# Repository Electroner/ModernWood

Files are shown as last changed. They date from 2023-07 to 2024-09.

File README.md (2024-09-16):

# ModernWood keyboard  

En este repositorio encontrarás desde los datasheet de cada parte que he usado hasta los archivos originales del AutoCAD, con todos los archivos descargados deberías ser capaz de poder crear y manufacturar este teclado sin ningún problema.

Este teclado usa un ESP32-S3 como controlador y un decodificador/Demultiplexor 74HC154D 4-a-16, Suficiente para conseguir un tiempo de polling igual o superior a los mejores teclados comerciales actuales (20kHz). Pruebas realizadas con el código actual. Además se ha decidido "prescindir" de un teclado numérico real, y lo que se ha hecho es conectar los números del numpad a los números de la parte superior del teclado, por lo que las teclas tanto del numpad como los de la parte superior son los mismos, al igual con el intro y "." (Ver Esquemática).

Para el cuerpo del teclado se ha optado por omitir de forma completa el Plate o panel superior, ya que dificulta el mantenimiento y el montaje. Se ha optado solo por poner una ventana de metacrilato en la parte de la electrónica para cubrirla de forma semicompleja y protegerla de golpes. La base del teclado es de madera. Esta será la que más guste al usuario, aunque se recomiendan jatoba, sucupira o mansonia.

Este además dispone de una pantalla donde se encontraran todas las configuraciones del teclado, además de la opción para habilitar o deshabilitar el funcionamiento por bluetooth.

## Imagenes

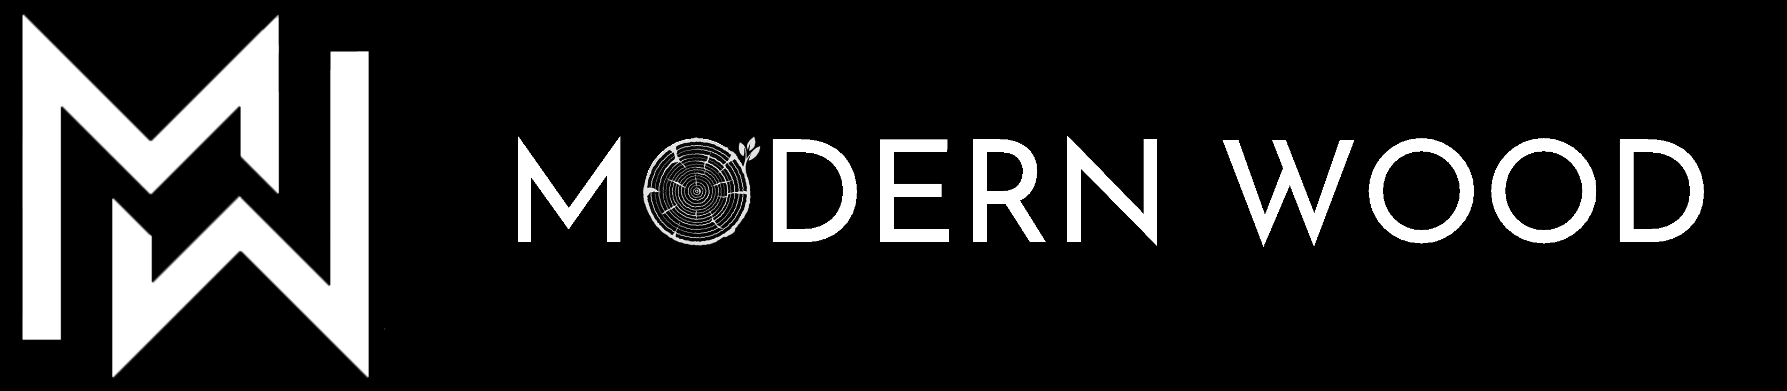
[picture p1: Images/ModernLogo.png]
TECLADO


---------------------------------------------------------------------------------------------

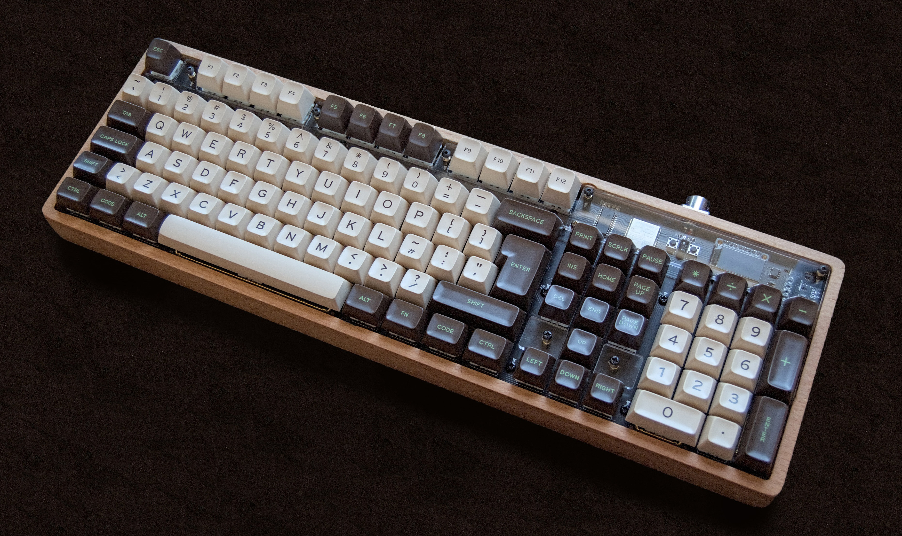
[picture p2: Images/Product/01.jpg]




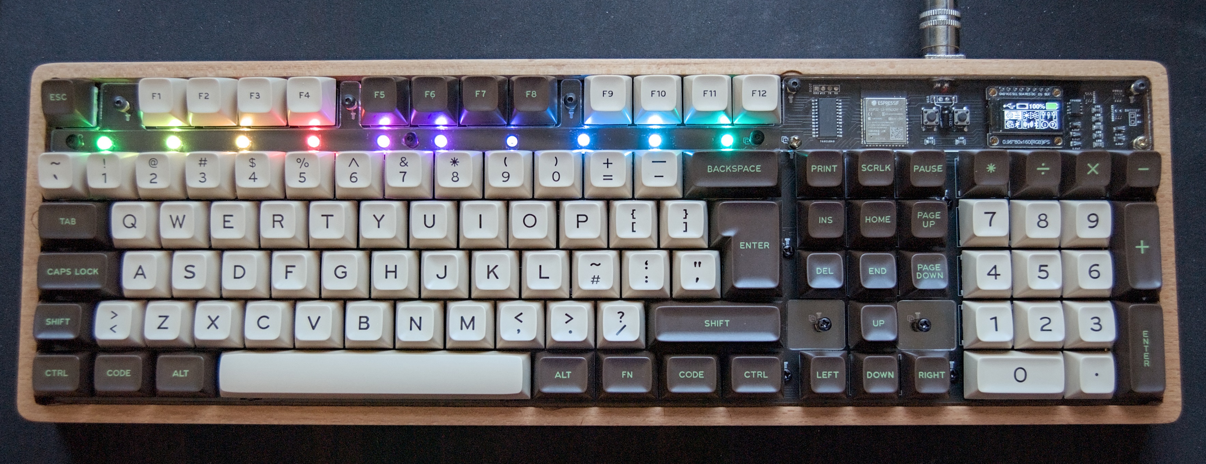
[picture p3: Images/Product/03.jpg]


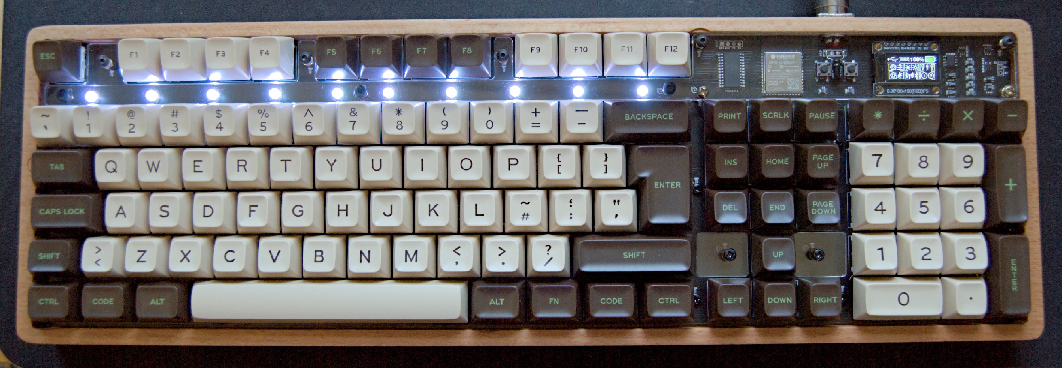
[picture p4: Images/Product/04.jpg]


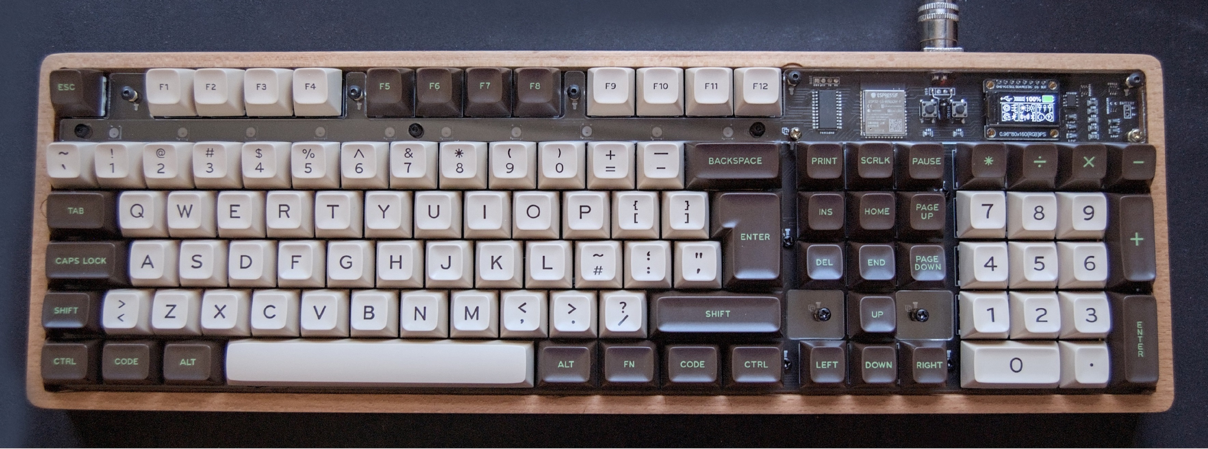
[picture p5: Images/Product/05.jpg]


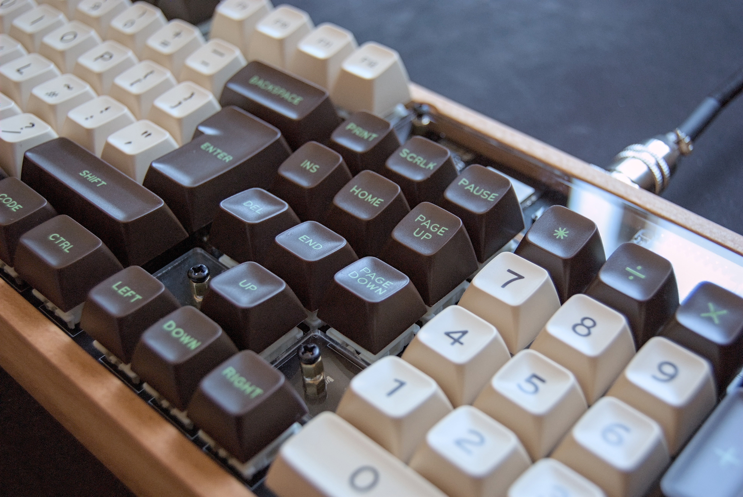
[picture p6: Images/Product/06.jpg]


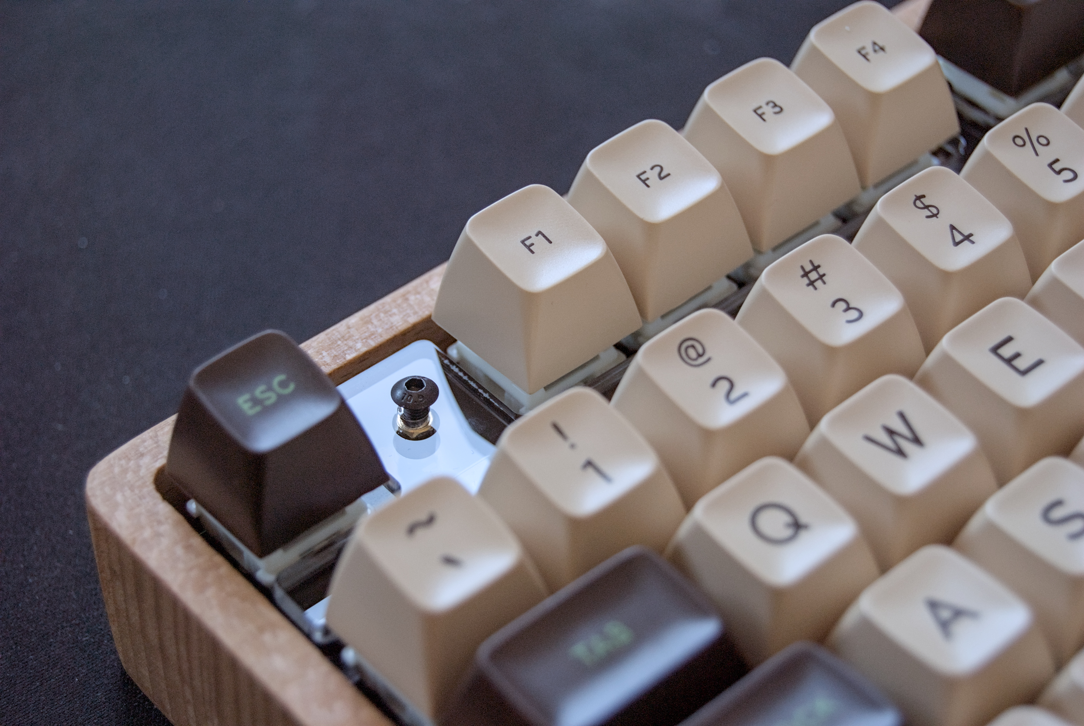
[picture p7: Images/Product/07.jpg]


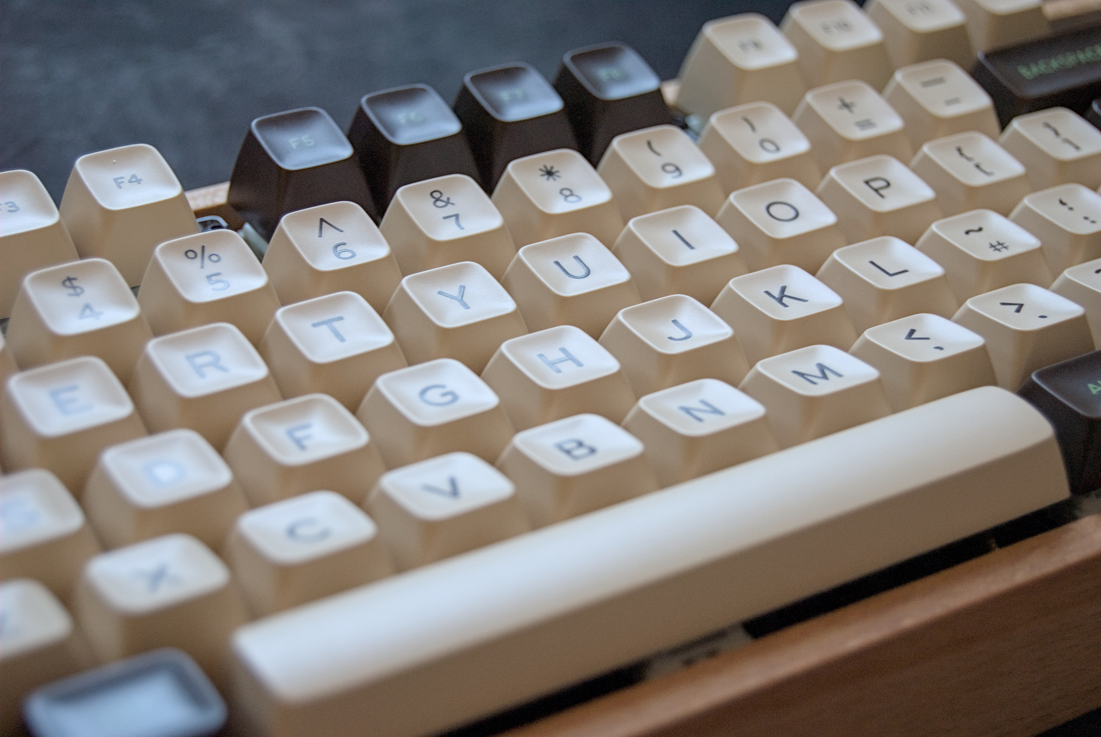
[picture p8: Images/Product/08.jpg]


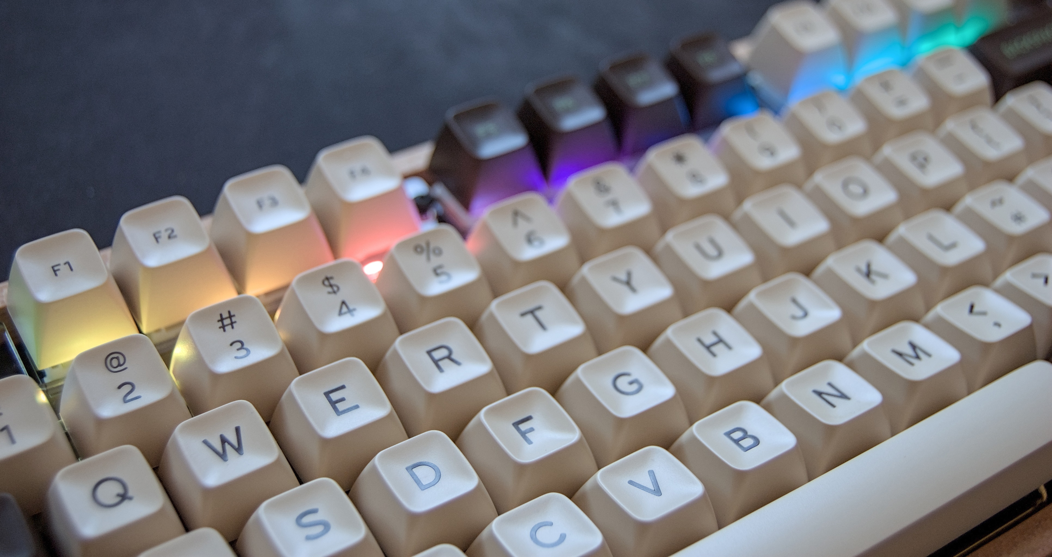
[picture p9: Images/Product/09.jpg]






---------------------------------------------------------------------------------------------

Vista Previa de la PCB:

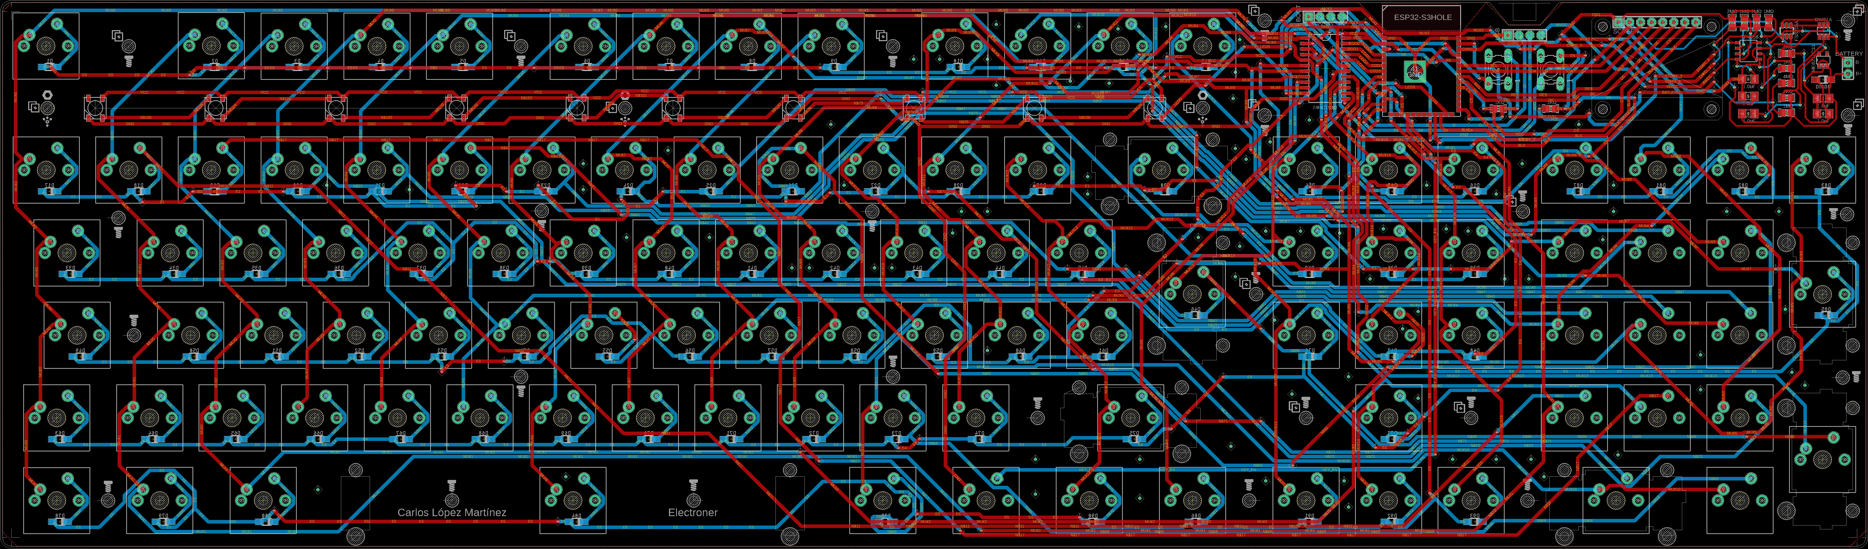
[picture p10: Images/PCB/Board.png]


Schematic:

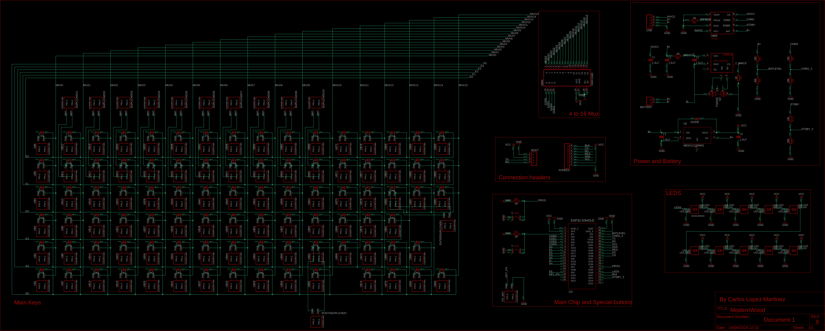
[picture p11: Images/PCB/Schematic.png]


### Piezas (Electronica)

```plaintext
PARTS

MUX 		| CD74HC154M96 (SOIC-24-300mil) | x1
CAPACITOR 	| 293D105X9035A2TE3 1uF (1206) 	| x5
RESISTOR	| RT0805BRD071KL 1k (0805)	| x5
RESISTOR	| RC0805FR-071ML 1M (0805)	| x3
RESISTOR	| 0805W8F2004T5E 2M (0805)	| x2
RESISTOR	| RC0805FR-073M74L 4M (0805)	| x1 (Is better if its 3.7M)
BATT PROTECTOR	| TP4056 (C725790) 		| x1
BATT PROTECTOR	| DW01A (SOT23-6) 		| x1
BATT PROTECTOR	| ME6211C33M5G (SOT-23-5) 	| x1
BATT PROTECTOR	| FS8205A (TSSOP-8) 		| x1
MAIN CHIP	| ESP32-S3 (SMD,18x25.5mm)	| x1
LEDS		| WS2812B (C114586)		| x10
DIODE		| 1N5819W (SOD123FL)		| x96
```

## Recursos Usados

-   [Alguna Investigacion y aprendizaje](https://github.com/w4ilun/pocket-keyboard)

Y varias paginas para datos concretos como funciones en eagle,ayuda con el bootloader y ejemplos de otros teclados.

-   [Ayuda con el bootloader](https://forum.arduino.cc/t/burning-bootloader-to-custom-board-atmega32u4/890015)
-   [Ayuda con el N-key](https://forum.arduino.cc/t/how-to-program-n-key-rollover-atmega32u4/938418)

## Software Usado

-   [Editor de Layaout Teclado](http://www.keyboard-layout-editor.com/)
-   [Autocad](https://www.autodesk.es/products/autocad/overview?term=1-YEAR&tab=subscription)
-   [FreeCad](https://www.freecadweb.org/)
-   [Eagle](https://www.autodesk.com/products/eagle/free-download)
-   [Componentes Eagle](https://componentsearchengine.com/)
-   [Produccion de la PCB](https://jlcpcb.com/)
-   [Compra de los componentes](https://lcsc.com/)
-   [Corte de metacrilato (Tienda Local)](https://ecoplasticlaser.com/)

## Actualizar las librerias

> [!IMPORTANT]  
> Si las librerias se actualizan en PlatformIO:
```
Cambiar 
#include <User_Setup.h> // en User_Setup_Select.h a:

//#include <User_Setup.h>
#include <../TFT_eSPI_Setups/Setup_ST7735_ESP80x160.h>
```

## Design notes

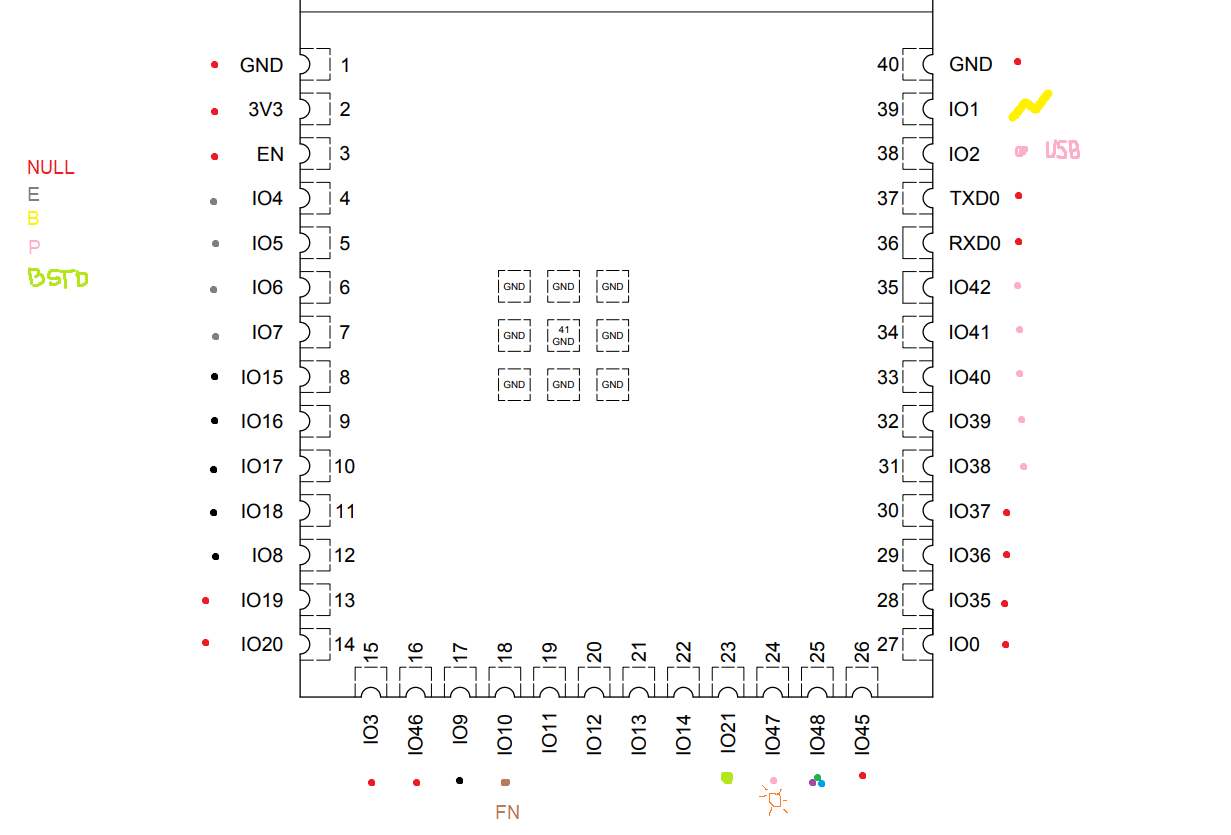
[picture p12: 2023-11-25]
Electronics/ESP32S3/ChipPins.png

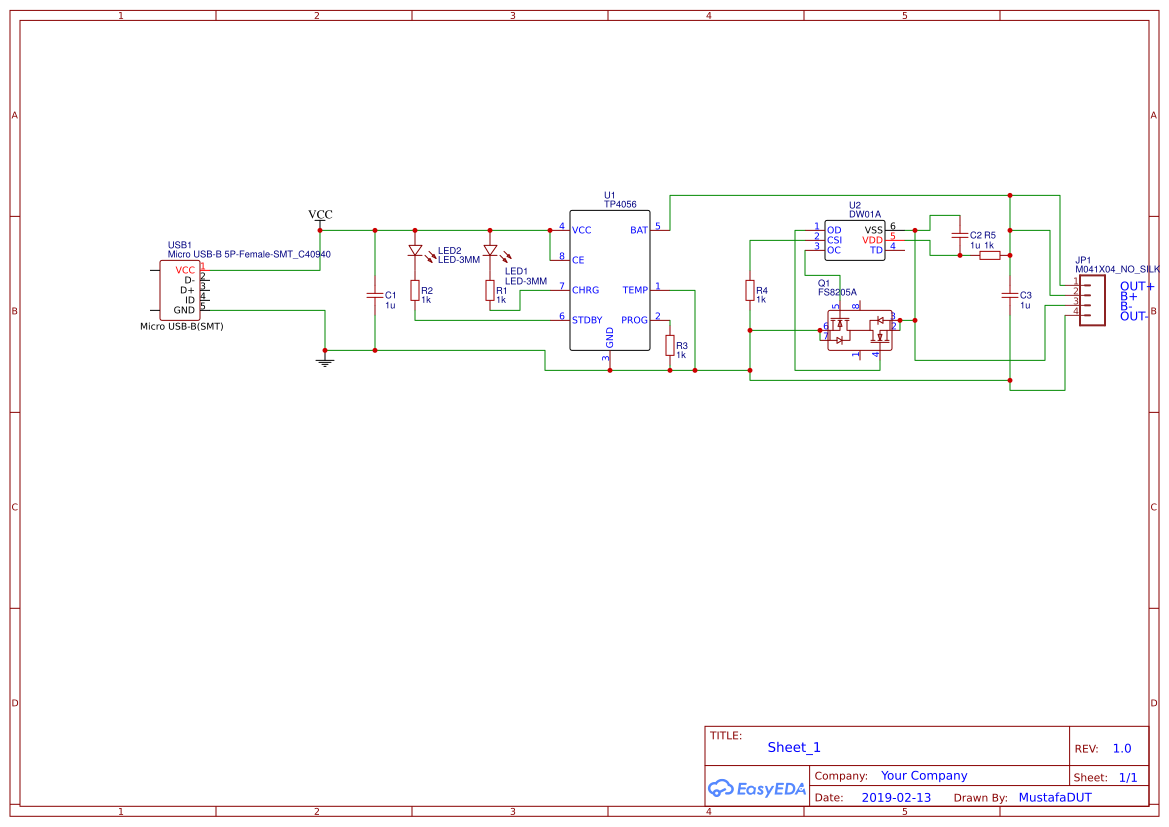
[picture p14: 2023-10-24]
Electronics/ESP32S3/Tp Schem.png

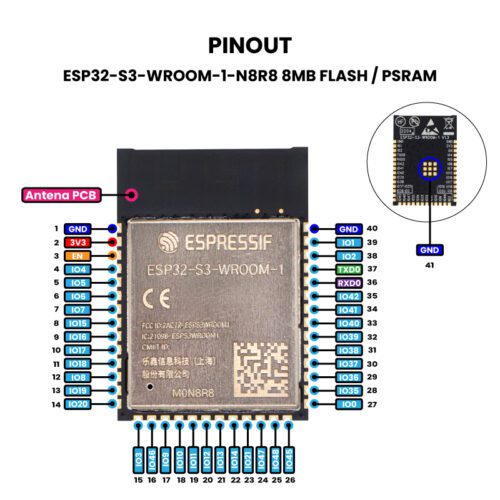
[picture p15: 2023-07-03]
Electronics/ESP32S3/125ae9fd-19d6-4643-9824-bebe2e77066b.jpeg

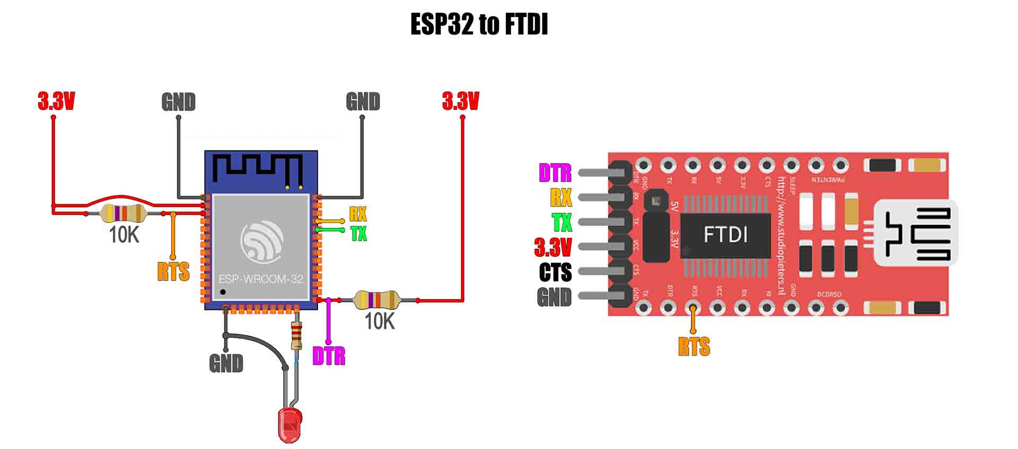
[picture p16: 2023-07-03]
Electronics/ESP32S3/sch_1.jpg

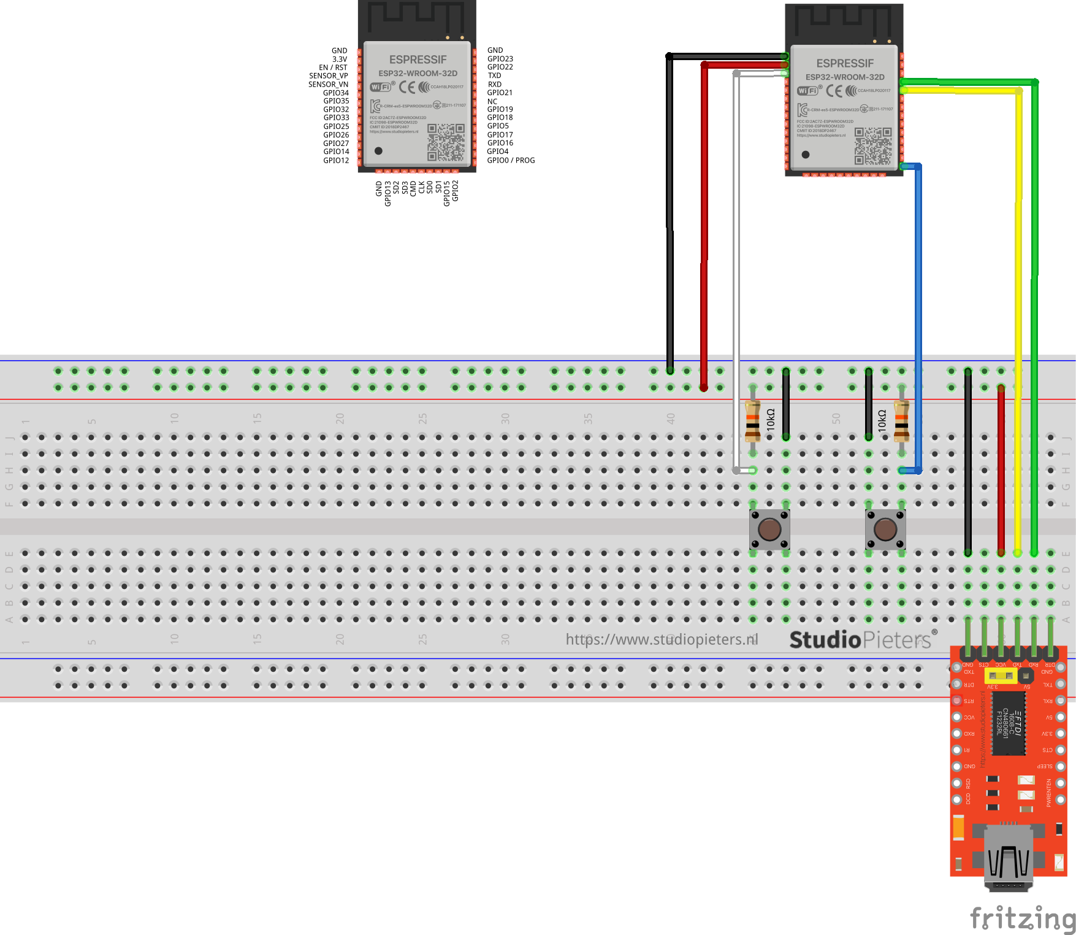
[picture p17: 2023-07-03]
Electronics/ESP32S3/ESP32-–-Program-default.png

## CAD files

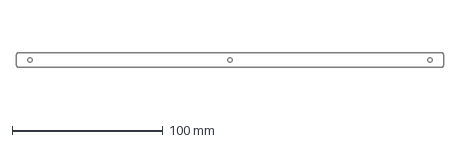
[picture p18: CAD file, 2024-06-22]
Planos/Difusor.dxf
284.3 x 9.70 mm

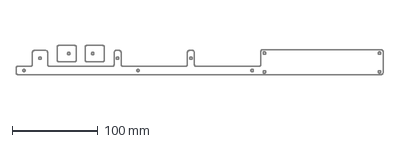
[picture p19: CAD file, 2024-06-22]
Planos/Protector.dxf
427.4 x 34.0 mm

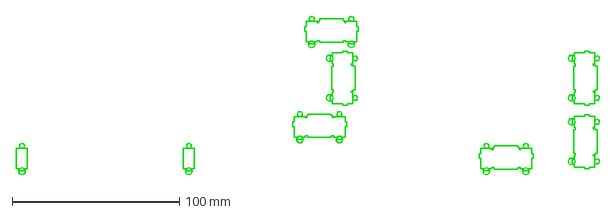
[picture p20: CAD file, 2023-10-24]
Planos/Agujeros Especiales.dxf
349.2 x 94.8 mm

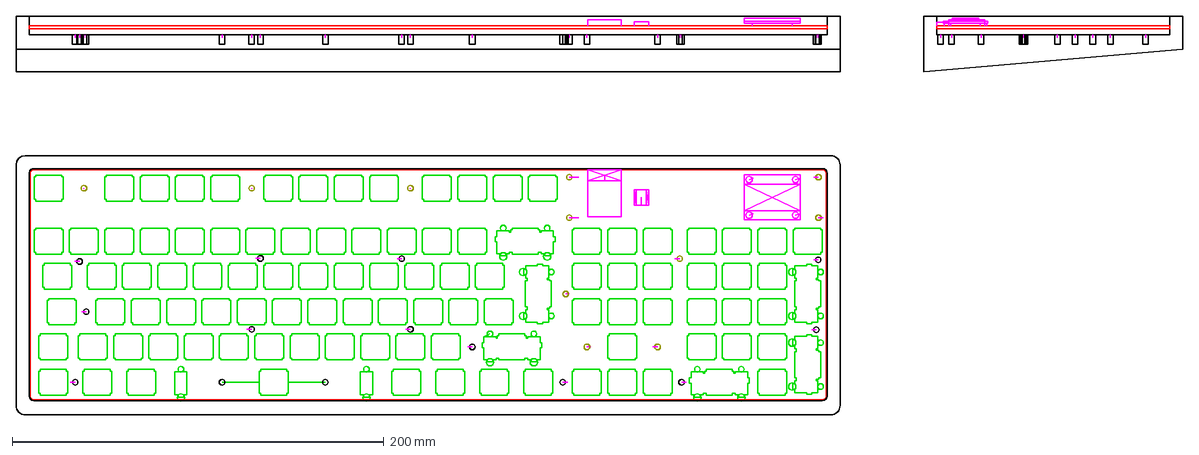
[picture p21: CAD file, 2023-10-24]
Planos/Modern Wood.dxf
628.0 x 214.5 mm

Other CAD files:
Planos/Planos acotados.dwg
Planos/Modern Wood ICON.dwg
Planos/Difusor.dwg
Planos/Modern Wood.dwg
Planos/Protector.dwg

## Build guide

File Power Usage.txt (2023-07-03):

Power Usage
-----------

TFT LCD 0.96" 	: 13mA
ESP32S3			: 80mA
74hc154d		: 90mA
DM74LS154		: 14mA

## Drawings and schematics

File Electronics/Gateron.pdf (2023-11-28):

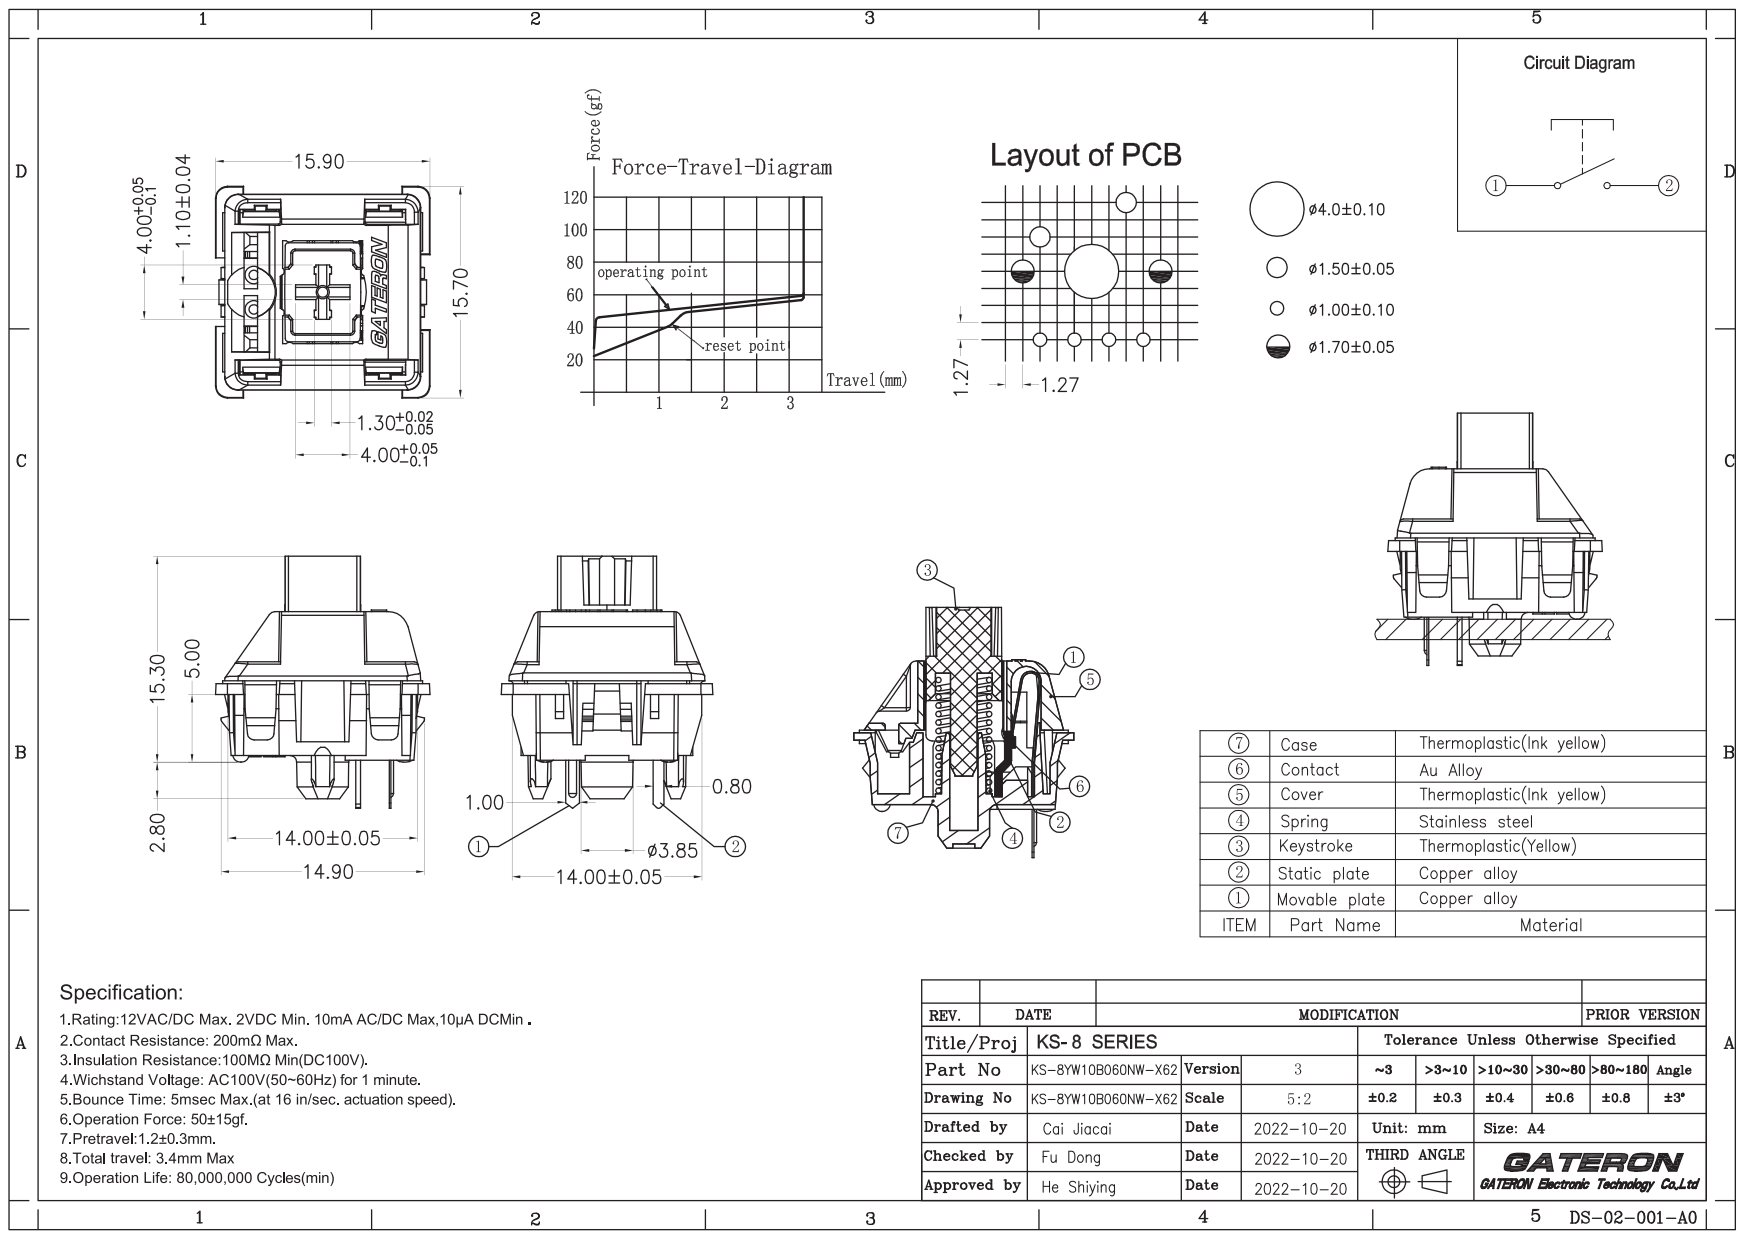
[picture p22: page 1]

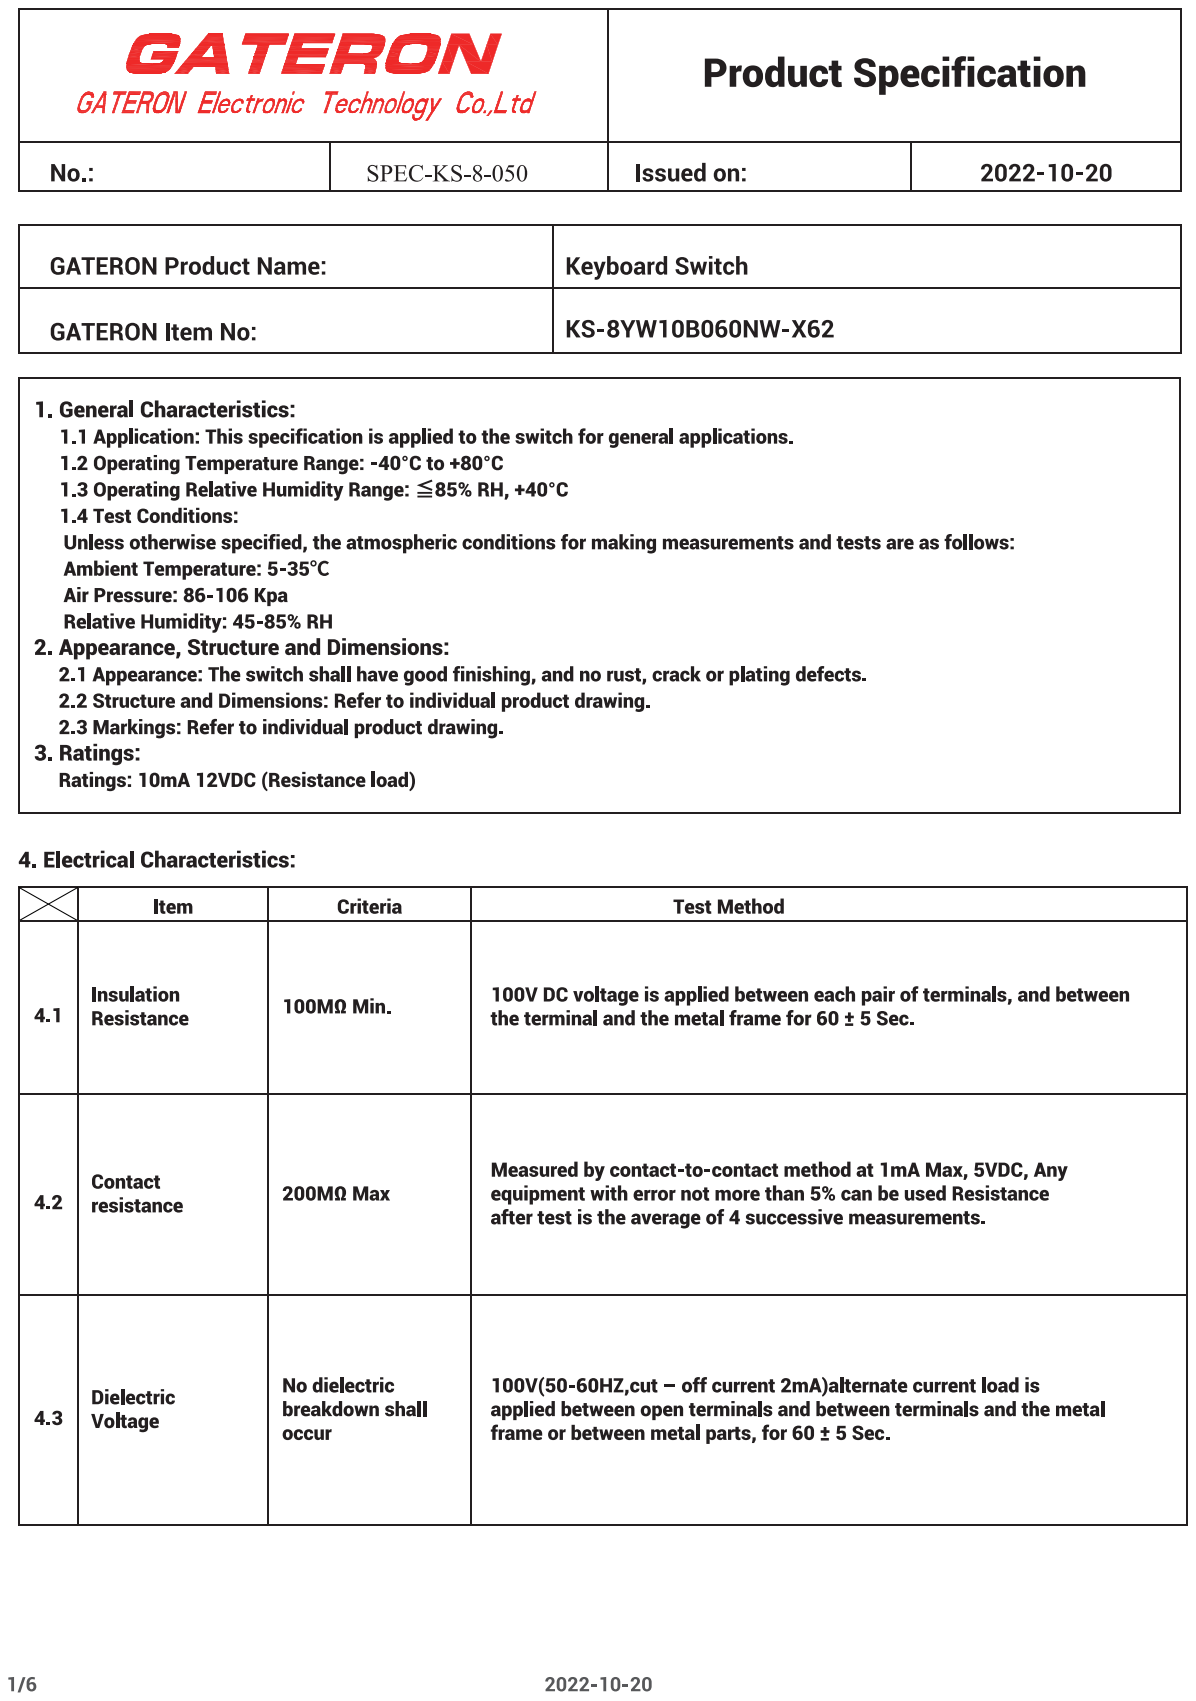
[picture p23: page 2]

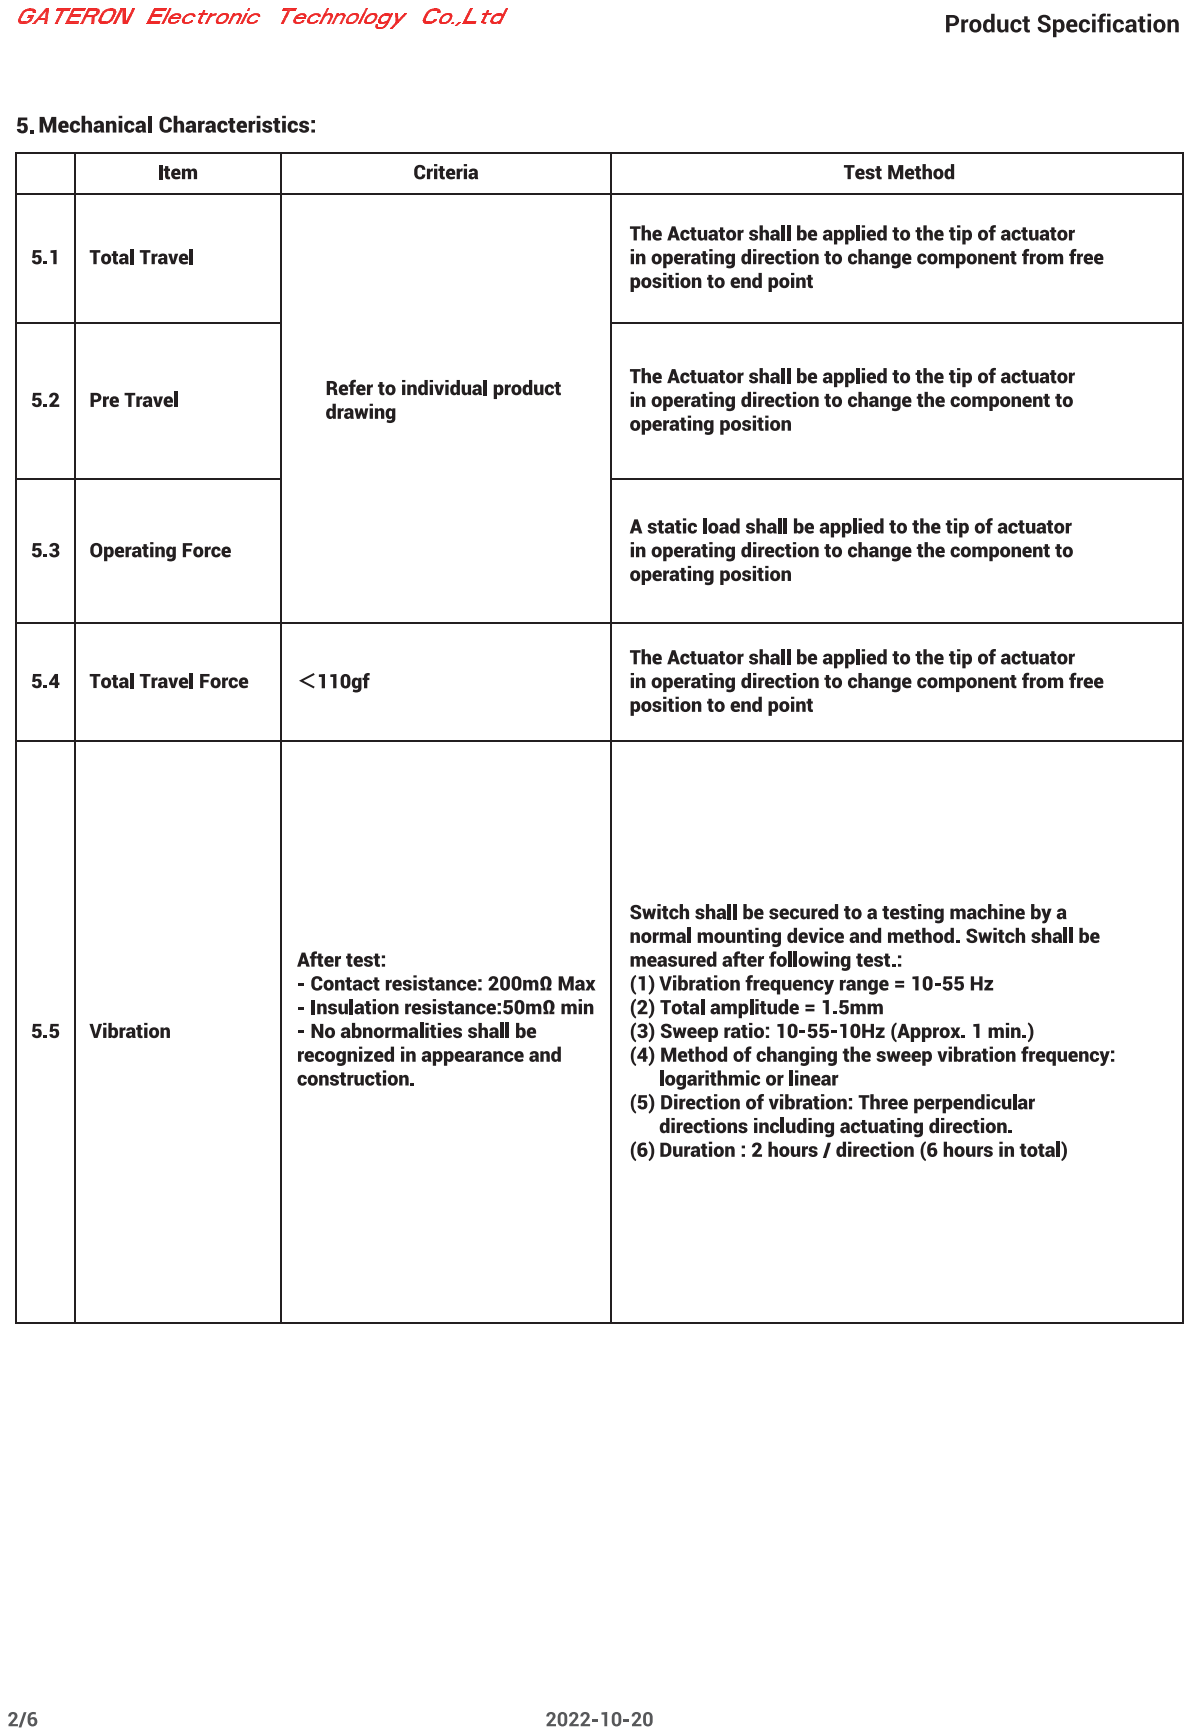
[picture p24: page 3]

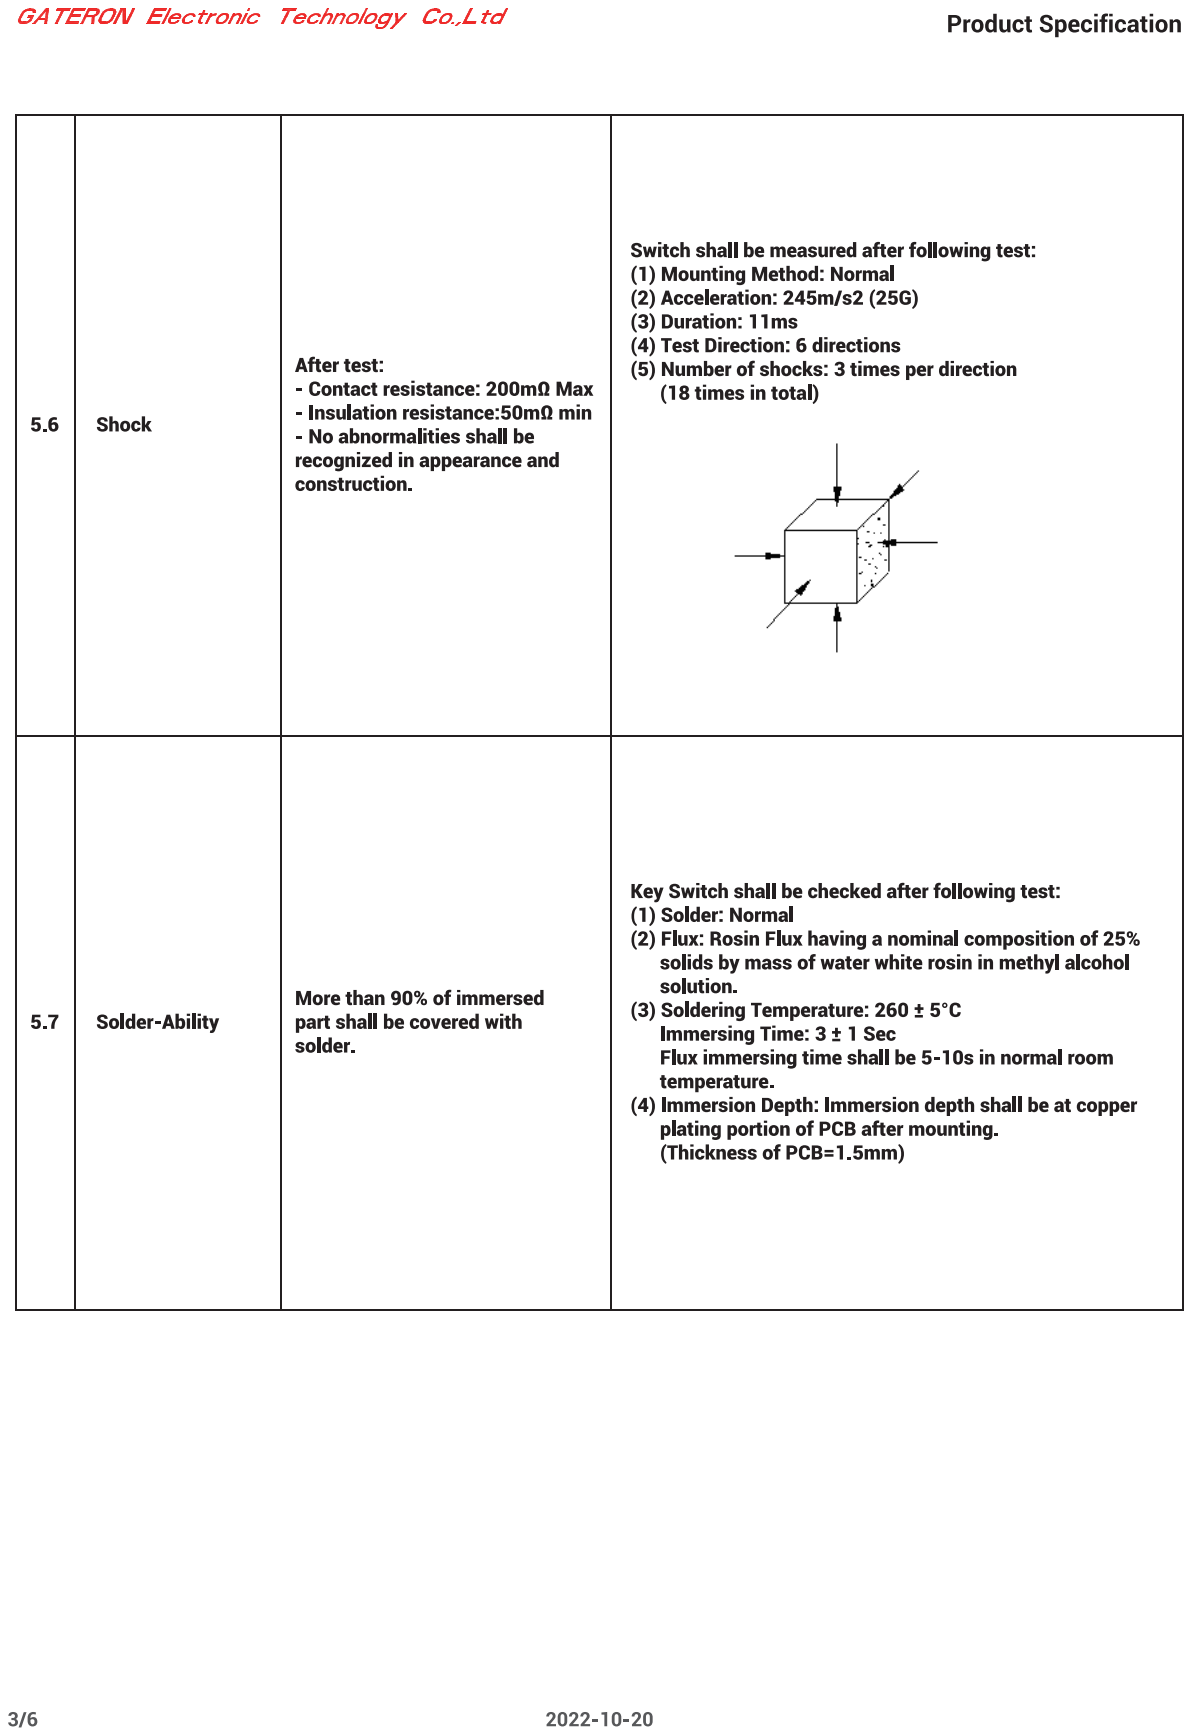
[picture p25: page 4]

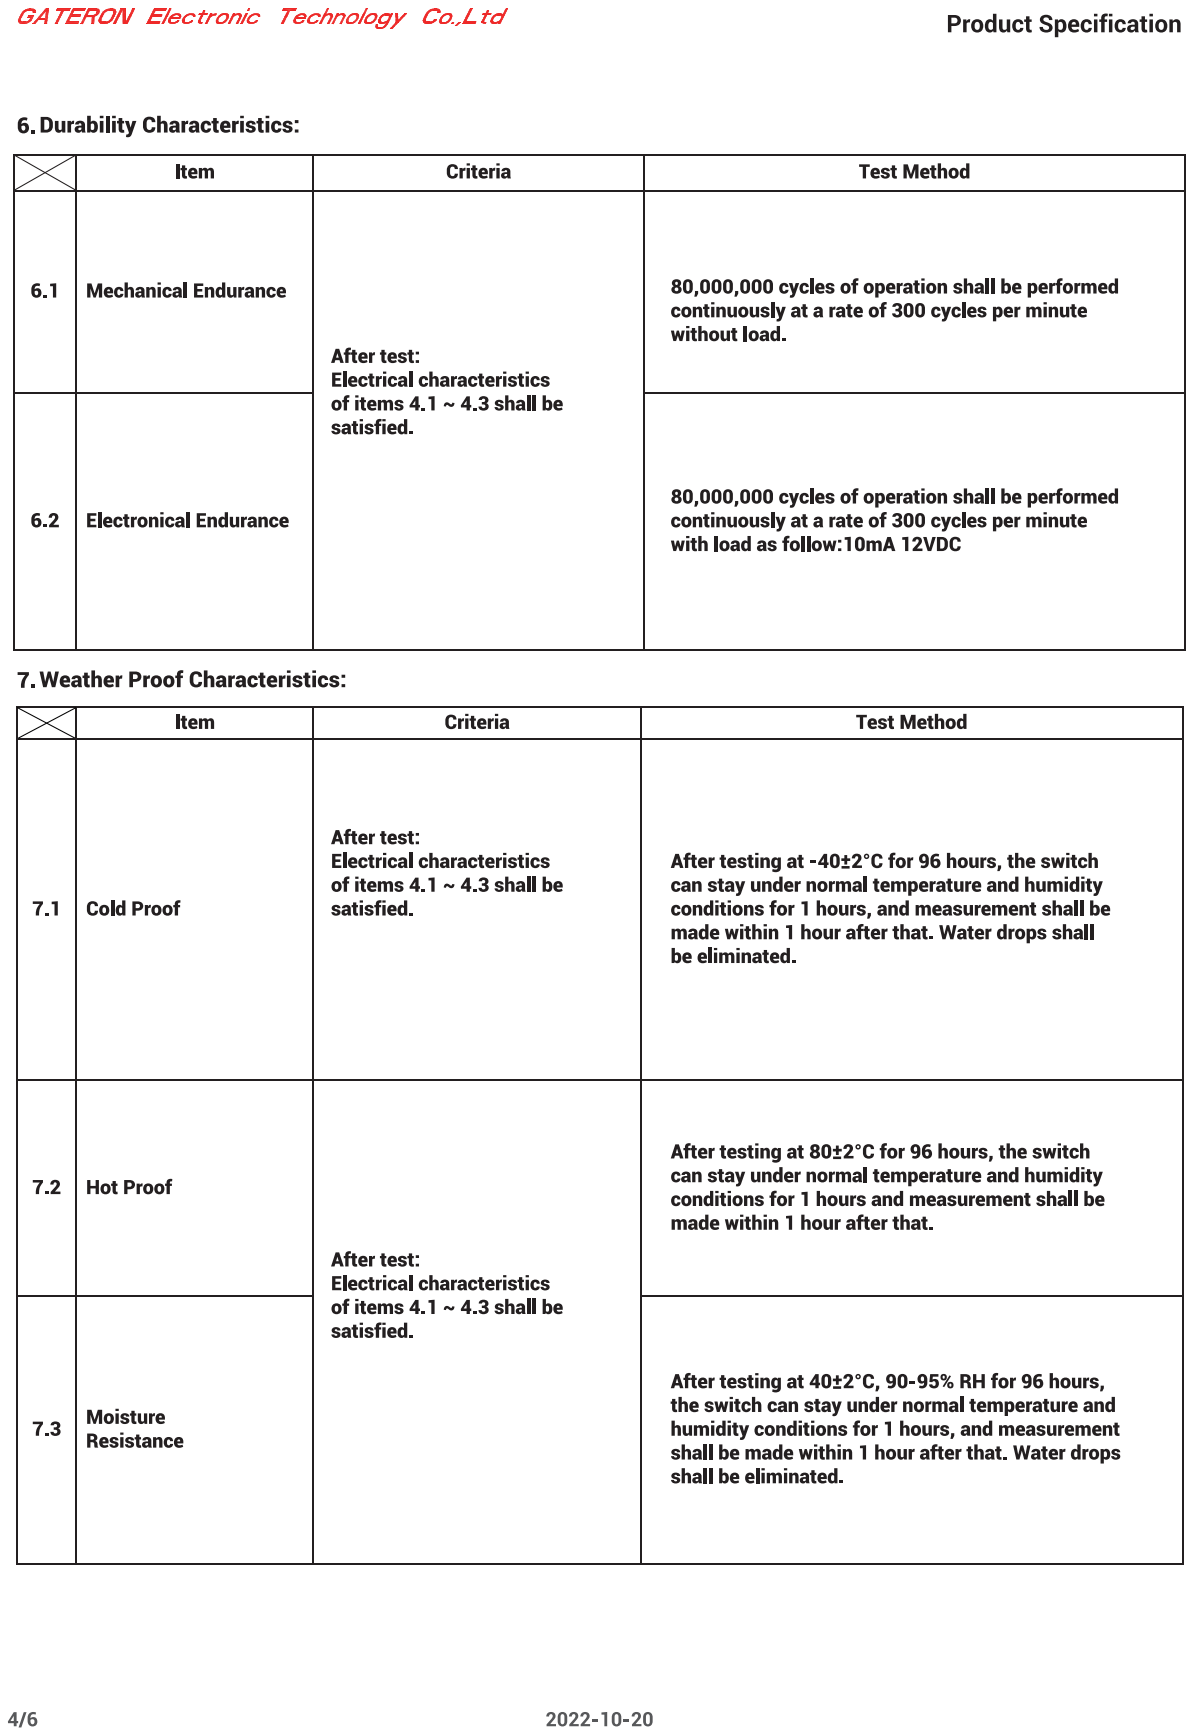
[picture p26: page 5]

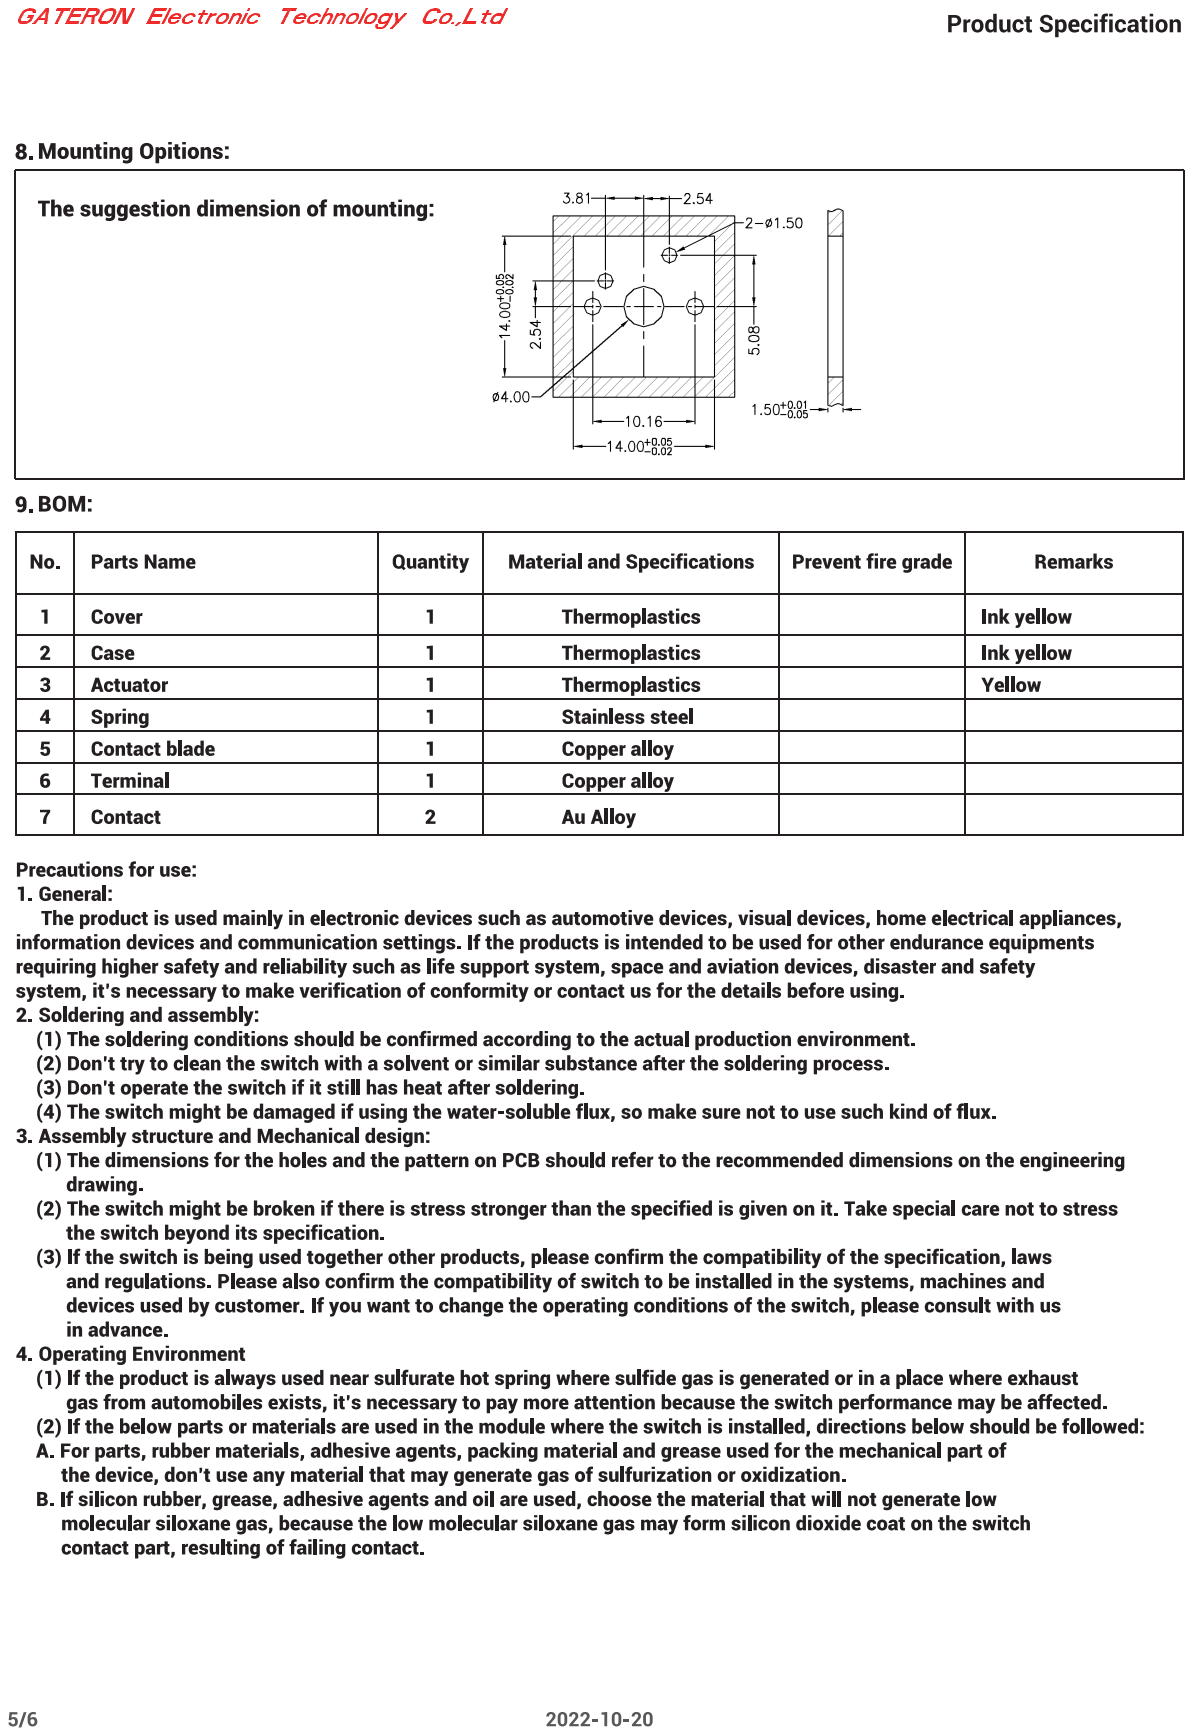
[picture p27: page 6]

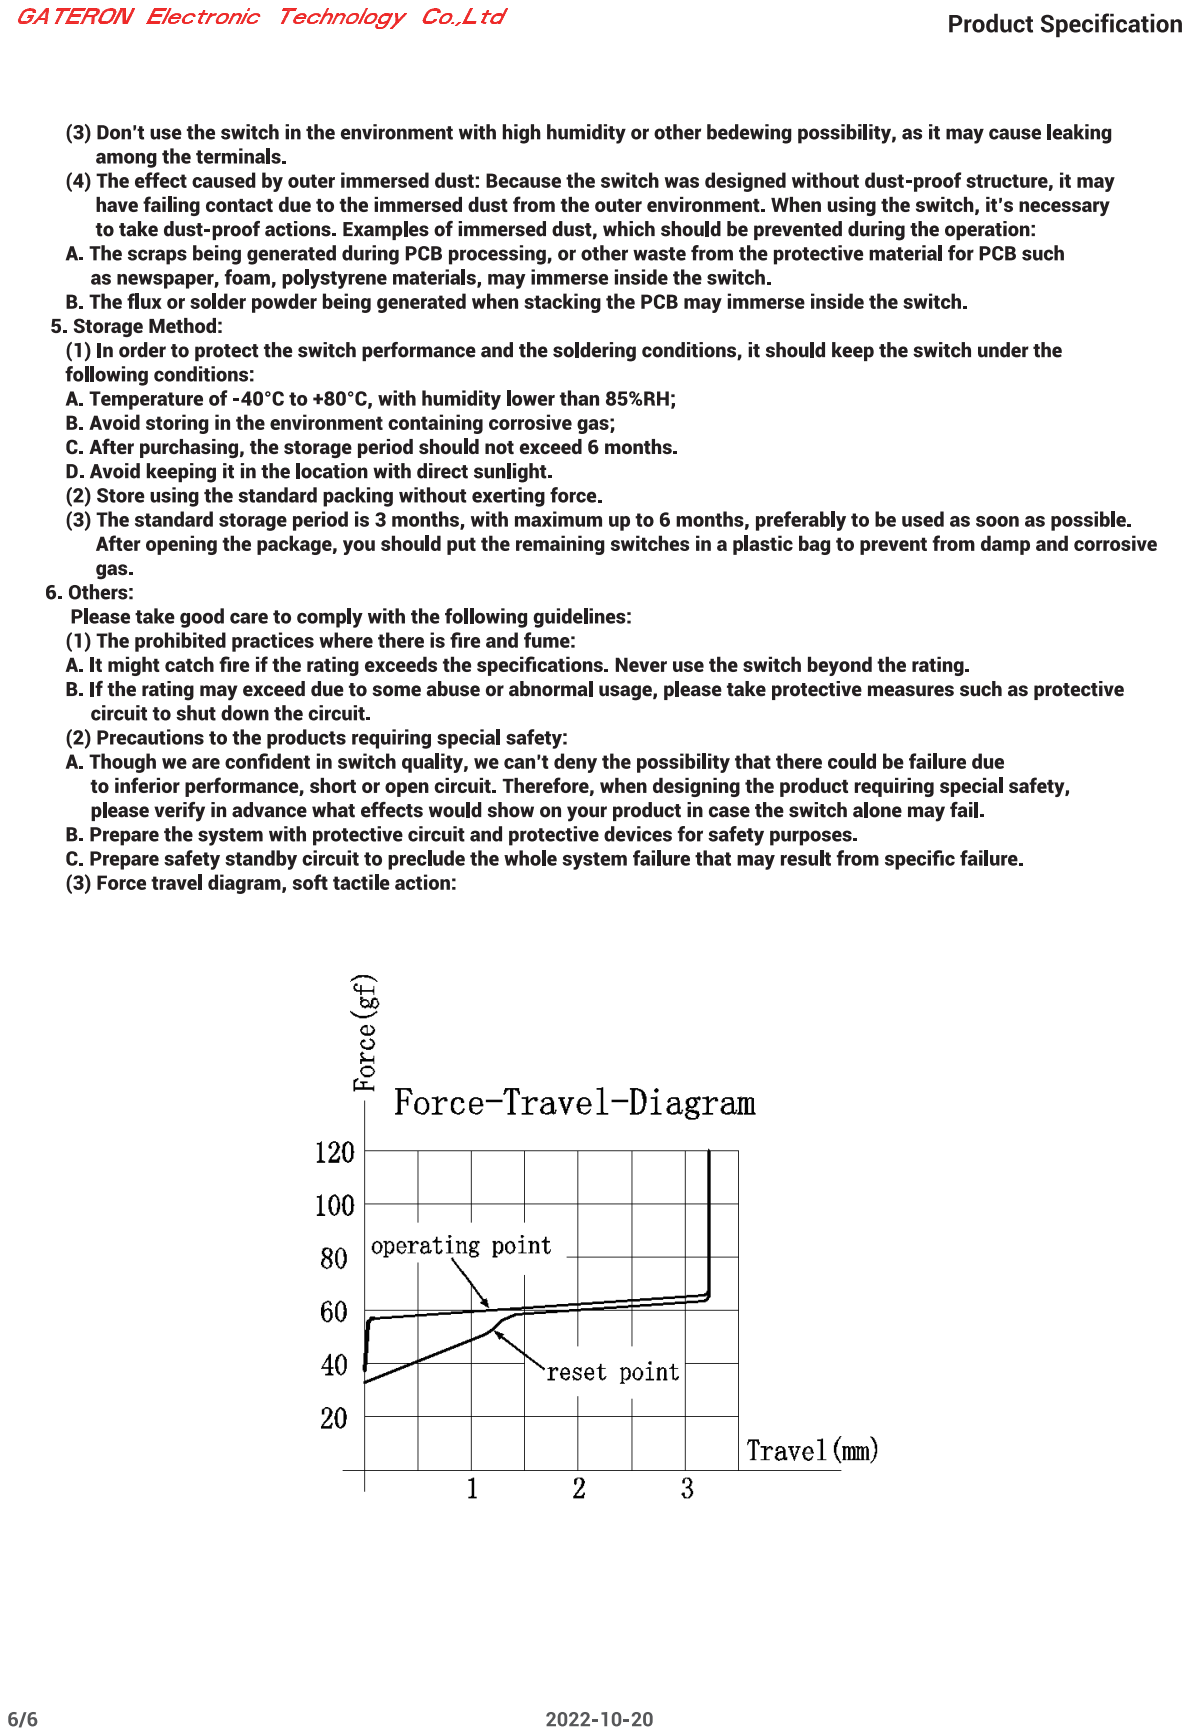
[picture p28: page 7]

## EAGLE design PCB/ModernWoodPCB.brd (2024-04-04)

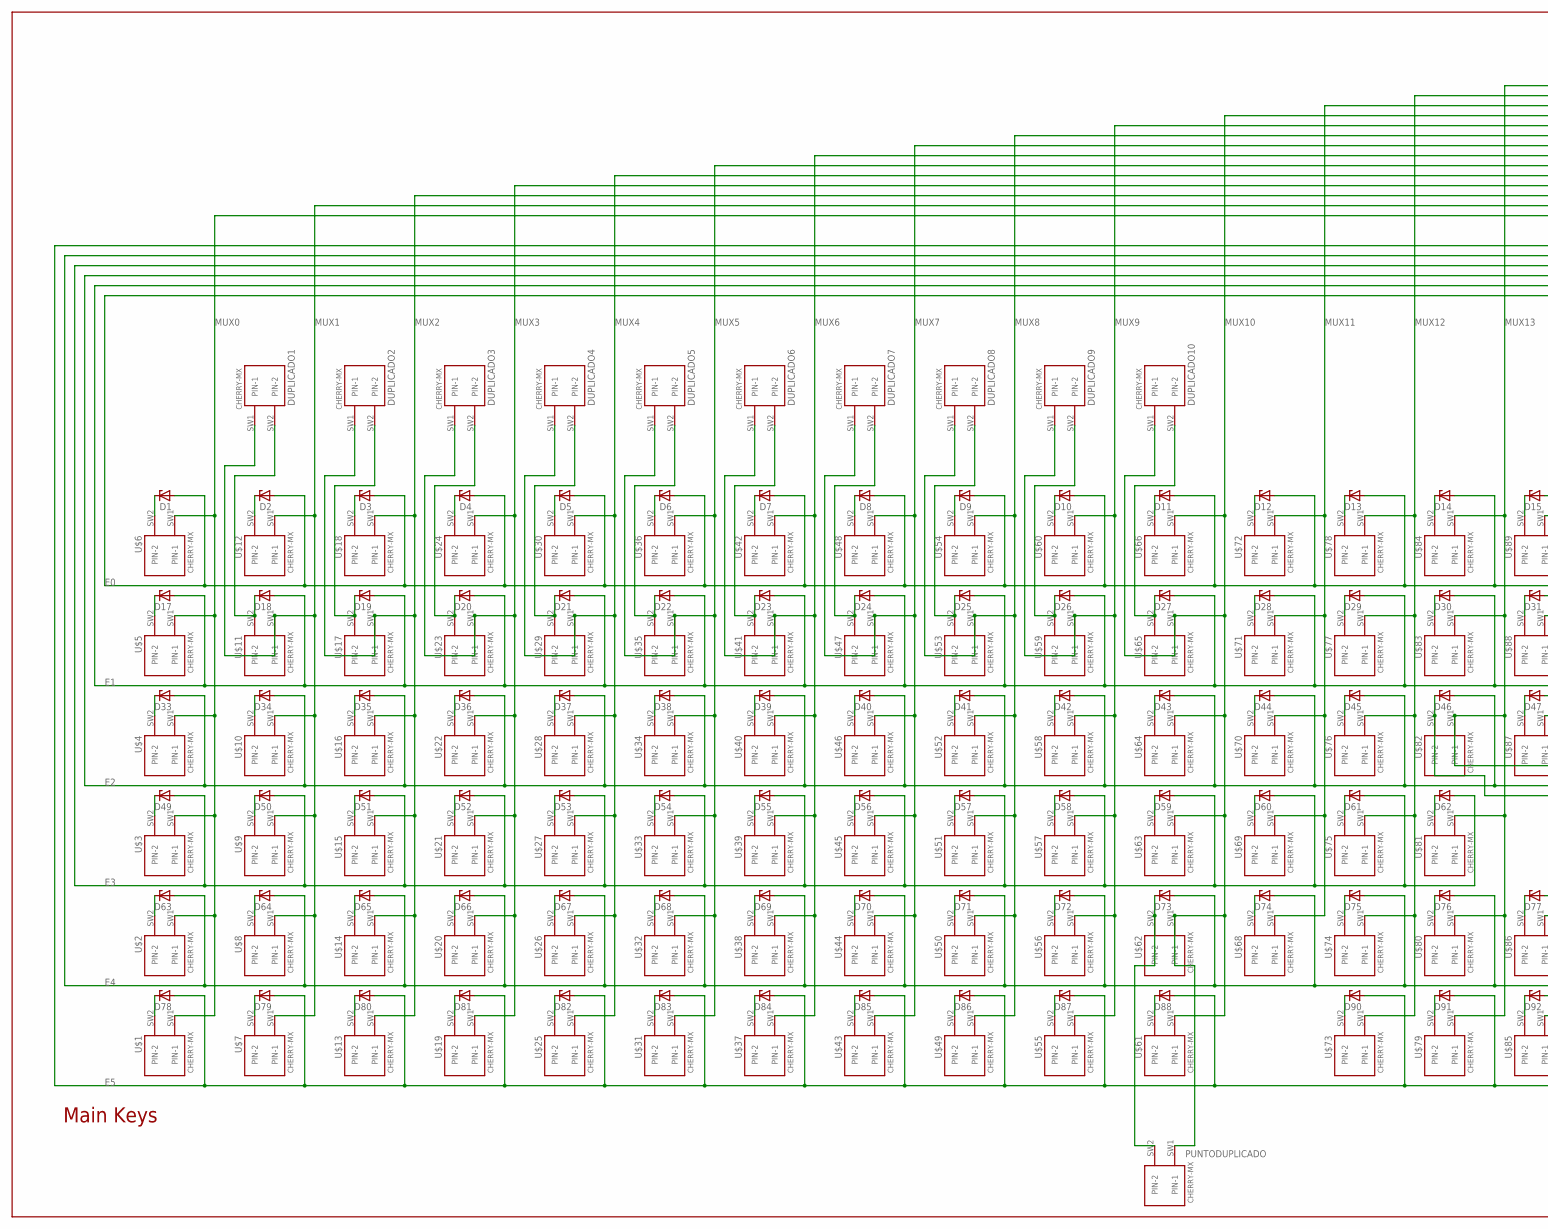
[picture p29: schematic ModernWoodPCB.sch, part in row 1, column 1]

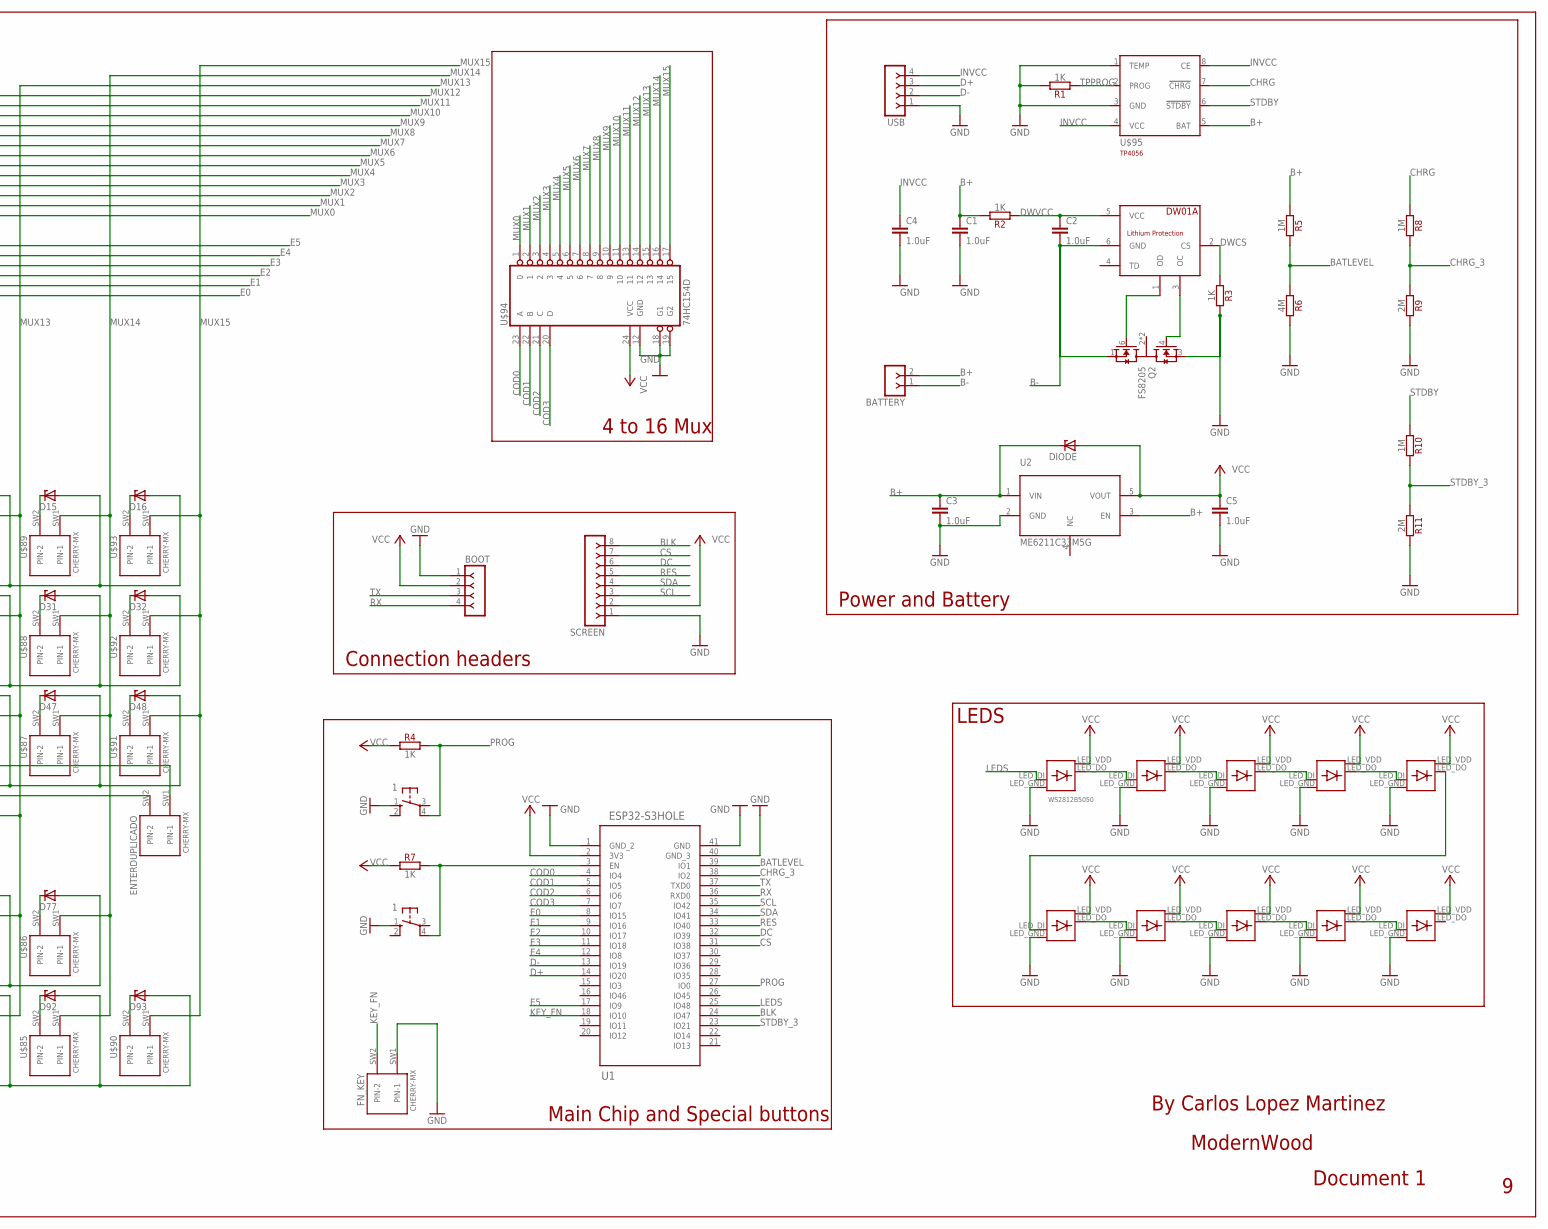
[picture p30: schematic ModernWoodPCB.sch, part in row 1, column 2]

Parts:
BATTERY: F-1X02-SIP-100-40; SIP-100-02-40
BOOT: BOOT; SIP-100-04-32
BUTTON, BUTTON1: 1; B3F-10XX
C1, C2, C3, C4, C5: 1.0uF; 1206
D1, D2, D3, D4, D5, D6, D7, D8, D9, D10, D11, D12, D13, D14, D15, D16, D17, D18, D19, D20, D21, D22, D23, D24, D25, D26, D27, D28, D29, D30, D31, D32, D33, D34, D35, D36, D37, D38, D39, D40, D41, D42, D43, D44, D45, D46, D47, D48, D49, D50, D51, D52, D53, D54, D55, D56, D57, D58, D59, D60, D61, D62, D63, D64, D65, D66, D67, D68, D69, D70, D71, D72, D73, D74, D75, D76, D77, D78, D79, D80, D81, D82, D83, D84, D85, D86, D87, D88, D90, D91, D92, D93: ZENER-DIODE-SOD123; SOD123FL
DIODE: ZENER-DIODE-SOD123; SOD123FL
DUPLICADO1, DUPLICADO2, DUPLICADO3, DUPLICADO4, DUPLICADO5, DUPLICADO6, DUPLICADO7, DUPLICADO8, DUPLICADO9, DUPLICADO10: CHERRY-MX
ENTERDUPLICADO: CHERRY-MX
FN_KEY: CHERRY-MX
PUNTODUPLICADO: CHERRY-MX
Q2: FS8205; SOT95P280X145-6N
R1, R2, R3, R4, R7: 1K; R-0805
R5, R8, R10: 1M; R-0805
R6: 4M; R-0805
R9, R11: 2M; R-0805
SCREEN: F-1X08-SIP-100-40; SIP-100-08-40
U1: ESP32-S3HOLE
U2: ME6211C33M5G
U$1, U$2, U$3, U$4, U$5, U$6, U$7, U$8, U$9, U$10, U$11, U$12, U$13, U$14, U$15, U$16, U$17, U$18, U$19, U$20, U$21, U$22, U$23, U$24, U$25, U$26, U$27, U$28, U$29, U$30, U$31, U$32, U$33, U$34, U$35, U$36, U$37, U$38, U$39, U$40, U$41, U$42, U$43, U$44, U$45, U$46, U$47, U$48, U$49, U$50, U$51, U$52, U$53, U$54, U$55, U$56, U$57, U$58, U$59, U$60, U$61, U$62, U$63, U$64, U$65, U$66, U$68, U$69, U$70, U$71, U$72, U$73, U$74, U$75, U$76, U$77, U$78, U$79, U$80, U$81, U$82, U$83, U$84, U$85, U$86, U$87, U$88, U$89, U$90, U$91, U$92, U$93: CHERRY-MX
U$67, U$97, U$98, U$99, U$100, U$101, U$102, U$103, U$104, U$105: WS2812B5050
U$94: 74HC154D
U$95: TP4056; SOT23-8
U$96: DW01A; SOT23-6
USB: F-1X04-SIP-100-32; SIP-100-04-32

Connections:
B+: BATTERY.2, C1.1, C3.1, DIODE.C, R2.2, R5.1, U2.1 (VIN), U2.3 (EN), U$95.5 (BAT)
B-: BATTERY.1, C2.2, Q2.1 (S1), U$96.6 (GND)
BATLEVEL: R5.2, R6.1, U1.39 (IO1)
BLK: SCREEN.8, U1.24 (IO47)
CHRG: R8.1, U$95.7 (!CHRG)
CHRG_3: R8.2, R9.1, U1.38 (IO2)
COD0: U1.4 (IO4), U$94.23 (A)
COD1: U1.5 (IO5), U$94.22 (B)
COD2: U1.6 (IO6), U$94.21 (C)
COD3: U1.7 (IO7), U$94.20 (D)
CS: SCREEN.7, U1.31 (IO38)
D+: U1.14 (IO20), USB.3
D-: U1.13 (IO19), USB.2
DC: SCREEN.6, U1.32 (IO39)
DWCS: R3.1, U$96.2 (CS)
DWVCC: C2.1, R2.1, U$96.5 (VCC)
E0: D1.A, D2.A, D3.A, D4.A, D5.A, D6.A, D7.A, D8.A, D9.A, D10.A, D11.A, D12.A, D13.A, D14.A, D15.A, D16.A, U1.8 (IO15)
E1: D17.A, D18.A, D19.A, D20.A, D21.A, D22.A, D23.A, D24.A, D25.A, D26.A, D27.A, D28.A, D29.A, D30.A, D31.A, D32.A, U1.9 (IO16)
E2: D33.A, D34.A, D35.A, D36.A, D37.A, D38.A, D39.A, D40.A, D41.A, D42.A, D43.A, D44.A, D45.A, D46.A, D47.A, D48.A, U1.10 (IO17)
E3: D49.A, D50.A, D51.A, D52.A, D53.A, D54.A, D55.A, D56.A, D57.A, D58.A, D59.A, D60.A, D61.A, D62.A, U1.11 (IO18)
E4: D63.A, D64.A, D65.A, D66.A, D67.A, D68.A, D69.A, D70.A, D71.A, D72.A, D73.A, D74.A, D75.A, D76.A, D77.A, U1.12 (IO8)
E5: D78.A, D79.A, D80.A, D81.A, D82.A, D83.A, D84.A, D85.A, D86.A, D87.A, D88.A, D90.A, D91.A, D92.A, D93.A, U1.17 (IO9)
EN: BUTTON1.4 (P1), R7.2, U1.3 (EN)
GND: BOOT.1, BUTTON.1 (S), BUTTON1.1 (S), C1.2, C3.2, C4.2, C5.2, FN_KEY.SW1 (PIN-1), Q2.3 (S2), R1.2, R3.2, R6.2, R9.2, R11.2, SCREEN.1, U1.1 (GND_2), U1.40 (GND_3), U1.41 (GND), U2.2 (GND), U$67.LED_GND, U$94.12 (GND), U$94.18 (G1), U$94.19 (G2), U$95.1 (TEMP), U$95.3 (GND), U$97.LED_GND, U$98.LED_GND, U$99.LED_GND, U$100.LED_GND, U$101.LED_GND, U$102.LED_GND, U$103.LED_GND, U$104.LED_GND, U$105.LED_GND, USB.1
INVCC: C4.1, U$95.4 (VCC), U$95.8 (CE), USB.4
KEY_FN: FN_KEY.SW2 (PIN-2), U1.18 (IO10)
LEDS: U1.25 (IO48), U$67.LED_DI
MUX0: U$1.SW1 (PIN-1), U$2.SW1 (PIN-1), U$3.SW1 (PIN-1), U$4.SW1 (PIN-1), U$5.SW1 (PIN-1), U$6.SW1 (PIN-1), U$94.1 (0)
MUX1: DUPLICADO1.SW1 (PIN-1), U$7.SW1 (PIN-1), U$8.SW1 (PIN-1), U$9.SW1 (PIN-1), U$10.SW1 (PIN-1), U$11.SW1 (PIN-1), U$12.SW1 (PIN-1), U$94.2 (1)
MUX2: DUPLICADO2.SW1 (PIN-1), U$13.SW1 (PIN-1), U$14.SW1 (PIN-1), U$15.SW1 (PIN-1), U$16.SW1 (PIN-1), U$17.SW1 (PIN-1), U$18.SW1 (PIN-1), U$94.3 (2)
MUX3: DUPLICADO3.SW1 (PIN-1), U$19.SW1 (PIN-1), U$20.SW1 (PIN-1), U$21.SW1 (PIN-1), U$22.SW1 (PIN-1), U$23.SW1 (PIN-1), U$24.SW1 (PIN-1), U$94.4 (3)
MUX4: DUPLICADO4.SW1 (PIN-1), U$25.SW1 (PIN-1), U$26.SW1 (PIN-1), U$27.SW1 (PIN-1), U$28.SW1 (PIN-1), U$29.SW1 (PIN-1), U$30.SW1 (PIN-1), U$94.5 (4)
MUX5: DUPLICADO5.SW1 (PIN-1), U$31.SW1 (PIN-1), U$32.SW1 (PIN-1), U$33.SW1 (PIN-1), U$34.SW1 (PIN-1), U$35.SW1 (PIN-1), U$36.SW1 (PIN-1), U$94.6 (5)
MUX6: DUPLICADO6.SW1 (PIN-1), U$37.SW1 (PIN-1), U$38.SW1 (PIN-1), U$39.SW1 (PIN-1), U$40.SW1 (PIN-1), U$41.SW1 (PIN-1), U$42.SW1 (PIN-1), U$94.7 (6)
MUX7: DUPLICADO7.SW1 (PIN-1), U$43.SW1 (PIN-1), U$44.SW1 (PIN-1), U$45.SW1 (PIN-1), U$46.SW1 (PIN-1), U$47.SW1 (PIN-1), U$48.SW1 (PIN-1), U$94.8 (7)
MUX8: DUPLICADO8.SW1 (PIN-1), U$49.SW1 (PIN-1), U$50.SW1 (PIN-1), U$51.SW1 (PIN-1), U$52.SW1 (PIN-1), U$53.SW1 (PIN-1), U$54.SW1 (PIN-1), U$94.9 (8)
MUX9: DUPLICADO9.SW1 (PIN-1), U$55.SW1 (PIN-1), U$56.SW1 (PIN-1), U$57.SW1 (PIN-1), U$58.SW1 (PIN-1), U$59.SW1 (PIN-1), U$60.SW1 (PIN-1), U$94.10 (9)
MUX10: DUPLICADO10.SW1 (PIN-1), PUNTODUPLICADO.SW1 (PIN-1), U$61.SW1 (PIN-1), U$62.SW1 (PIN-1), U$63.SW1 (PIN-1), U$64.SW1 (PIN-1), U$65.SW1 (PIN-1), U$66.SW1 (PIN-1), U$94.11 (10)
MUX11: U$68.SW1 (PIN-1), U$69.SW1 (PIN-1), U$70.SW1 (PIN-1), U$71.SW1 (PIN-1), U$72.SW1 (PIN-1), U$94.13 (11)
MUX12: U$73.SW1 (PIN-1), U$74.SW1 (PIN-1), U$75.SW1 (PIN-1), U$76.SW1 (PIN-1), U$77.SW1 (PIN-1), U$78.SW1 (PIN-1), U$94.14 (12)
MUX13: ENTERDUPLICADO.SW1 (PIN-1), U$79.SW1 (PIN-1), U$80.SW1 (PIN-1), U$81.SW1 (PIN-1), U$82.SW1 (PIN-1), U$83.SW1 (PIN-1), U$84.SW1 (PIN-1), U$94.15 (13)
MUX14: U$85.SW1 (PIN-1), U$86.SW1 (PIN-1), U$87.SW1 (PIN-1), U$88.SW1 (PIN-1), U$89.SW1 (PIN-1), U$94.16 (14)
MUX15: U$90.SW1 (PIN-1), U$91.SW1 (PIN-1), U$92.SW1 (PIN-1), U$93.SW1 (PIN-1), U$94.17 (15)
unnamed: D33.C, U$4.SW2 (PIN-2)
unnamed: D34.C, U$10.SW2 (PIN-2)
unnamed: D35.C, U$16.SW2 (PIN-2)
unnamed: D36.C, U$22.SW2 (PIN-2)
unnamed: D17.C, U$5.SW2 (PIN-2)
unnamed: D1.C, U$6.SW2 (PIN-2)
unnamed: D37.C, U$28.SW2 (PIN-2)
unnamed: D38.C, U$34.SW2 (PIN-2)
unnamed: D39.C, U$40.SW2 (PIN-2)
unnamed: D40.C, U$46.SW2 (PIN-2)
unnamed: D18.C, DUPLICADO1.SW2 (PIN-2), U$11.SW2 (PIN-2)
unnamed: D2.C, U$12.SW2 (PIN-2)
unnamed: D41.C, U$52.SW2 (PIN-2)
unnamed: D42.C, U$58.SW2 (PIN-2)
unnamed: D43.C, U$64.SW2 (PIN-2)
unnamed: D44.C, U$70.SW2 (PIN-2)
unnamed: D19.C, DUPLICADO2.SW2 (PIN-2), U$17.SW2 (PIN-2)
unnamed: D3.C, U$18.SW2 (PIN-2)
unnamed: D45.C, U$76.SW2 (PIN-2)
unnamed: D47.C, U$87.SW2 (PIN-2)
unnamed: D48.C, U$91.SW2 (PIN-2)
unnamed: D62.C, U$81.SW2 (PIN-2)
unnamed: D20.C, DUPLICADO3.SW2 (PIN-2), U$23.SW2 (PIN-2)
unnamed: D4.C, U$24.SW2 (PIN-2)
unnamed: D61.C, U$75.SW2 (PIN-2)
unnamed: D60.C, U$69.SW2 (PIN-2)
unnamed: D59.C, U$63.SW2 (PIN-2)
unnamed: D58.C, U$57.SW2 (PIN-2)
unnamed: D21.C, DUPLICADO4.SW2 (PIN-2), U$29.SW2 (PIN-2)
unnamed: D5.C, U$30.SW2 (PIN-2)
unnamed: Q2.6 (G1), U$96.1 (OD)
unnamed: Q2.4 (G2), U$96.3 (OC)
unnamed: U$97.LED_DO, U$98.LED_DI
unnamed: D57.C, U$51.SW2 (PIN-2)
unnamed: D56.C, U$45.SW2 (PIN-2)
unnamed: D55.C, U$39.SW2 (PIN-2)
unnamed: D54.C, U$33.SW2 (PIN-2)
unnamed: D22.C, DUPLICADO5.SW2 (PIN-2), U$35.SW2 (PIN-2)
unnamed: D6.C, U$36.SW2 (PIN-2)
unnamed: D53.C, U$27.SW2 (PIN-2)
unnamed: D52.C, U$21.SW2 (PIN-2)
unnamed: D51.C, U$15.SW2 (PIN-2)
unnamed: D50.C, U$9.SW2 (PIN-2)
unnamed: D23.C, DUPLICADO6.SW2 (PIN-2), U$41.SW2 (PIN-2)
unnamed: D7.C, U$42.SW2 (PIN-2)
unnamed: D49.C, U$3.SW2 (PIN-2)
unnamed: D63.C, U$2.SW2 (PIN-2)
unnamed: D64.C, U$8.SW2 (PIN-2)
unnamed: D65.C, U$14.SW2 (PIN-2)
unnamed: D24.C, DUPLICADO7.SW2 (PIN-2), U$47.SW2 (PIN-2)
unnamed: D8.C, U$48.SW2 (PIN-2)
unnamed: D66.C, U$20.SW2 (PIN-2)
unnamed: D67.C, U$26.SW2 (PIN-2)
unnamed: D68.C, U$32.SW2 (PIN-2)
unnamed: D69.C, U$38.SW2 (PIN-2)
unnamed: D25.C, DUPLICADO8.SW2 (PIN-2), U$53.SW2 (PIN-2)
unnamed: D9.C, U$54.SW2 (PIN-2)
unnamed: D70.C, U$44.SW2 (PIN-2)
unnamed: D71.C, U$50.SW2 (PIN-2)
unnamed: D72.C, U$56.SW2 (PIN-2)
unnamed: D74.C, U$68.SW2 (PIN-2)
unnamed: D26.C, DUPLICADO9.SW2 (PIN-2), U$59.SW2 (PIN-2)
unnamed: D10.C, U$60.SW2 (PIN-2)
unnamed: D75.C, U$74.SW2 (PIN-2)
unnamed: D73.C, PUNTODUPLICADO.SW2 (PIN-2), U$62.SW2 (PIN-2)
unnamed: D76.C, U$80.SW2 (PIN-2)
unnamed: D77.C, U$86.SW2 (PIN-2)
unnamed: D27.C, DUPLICADO10.SW2 (PIN-2), U$65.SW2 (PIN-2)
unnamed: D11.C, U$66.SW2 (PIN-2)
unnamed: D93.C, U$90.SW2 (PIN-2)
unnamed: D92.C, U$85.SW2 (PIN-2)
unnamed: D91.C, U$79.SW2 (PIN-2)
unnamed: D90.C, U$73.SW2 (PIN-2)
unnamed: D28.C, U$71.SW2 (PIN-2)
unnamed: D12.C, U$72.SW2 (PIN-2)
unnamed: U$98.LED_DO, U$99.LED_DI
unnamed: D88.C, U$61.SW2 (PIN-2)
unnamed: D87.C, U$55.SW2 (PIN-2)
unnamed: D86.C, U$49.SW2 (PIN-2)
unnamed: D29.C, U$77.SW2 (PIN-2)
unnamed: D13.C, U$78.SW2 (PIN-2)
unnamed: D85.C, U$43.SW2 (PIN-2)
unnamed: D84.C, U$37.SW2 (PIN-2)
unnamed: D83.C, U$31.SW2 (PIN-2)
unnamed: D46.C, ENTERDUPLICADO.SW2 (PIN-2), U$82.SW2 (PIN-2)
unnamed: D30.C, U$83.SW2 (PIN-2)
unnamed: D14.C, U$84.SW2 (PIN-2)
unnamed: D82.C, U$25.SW2 (PIN-2)
unnamed: D81.C, U$19.SW2 (PIN-2)
unnamed: D80.C, U$13.SW2 (PIN-2)
unnamed: D31.C, U$88.SW2 (PIN-2)
unnamed: D15.C, U$89.SW2 (PIN-2)
unnamed: D79.C, U$7.SW2 (PIN-2)
unnamed: D78.C, U$1.SW2 (PIN-2)
unnamed: D32.C, U$92.SW2 (PIN-2)
unnamed: D16.C, U$93.SW2 (PIN-2)
unnamed: U$99.LED_DO, U$100.LED_DI
unnamed: U$100.LED_DO, U$101.LED_DI
unnamed: U$101.LED_DO, U$102.LED_DI
unnamed: U$102.LED_DO, U$103.LED_DI
unnamed: U$103.LED_DO, U$104.LED_DI
unnamed: U$104.LED_DO, U$105.LED_DI
unnamed: U$67.LED_DO, U$97.LED_DI
PROG: BUTTON.4 (P1), R4.2, U1.27 (IO0)
RES: SCREEN.5, U1.33 (IO40)
RX: BOOT.4, U1.36 (RXD0)
SCL: SCREEN.3, U1.35 (IO42)
SDA: SCREEN.4, U1.34 (IO41)
STDBY: R10.1, U$95.6 (!STDBY)
STDBY_3: R10.2, R11.1, U1.23 (IO21)
TPPROG: R1.1, U$95.2 (PROG)
TX: BOOT.3, U1.37 (TXD0)
VCC: BOOT.2, C5.1, DIODE.A, R4.1, R7.1, SCREEN.2, U1.2 (3V3), U2.5 (VOUT), U$67.LED_VDD, U$94.24 (VCC), U$97.LED_VDD, U$98.LED_VDD, U$99.LED_VDD, U$100.LED_VDD, U$101.LED_VDD, U$102.LED_VDD, U$103.LED_VDD, U$104.LED_VDD, U$105.LED_VDD

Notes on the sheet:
ModernWood
Document 1
By Carlos Lopez Martinez
LEDS
Main Chip and Special buttons
Connection headers
Power and Battery
4 to 16 Mux
Main Keys

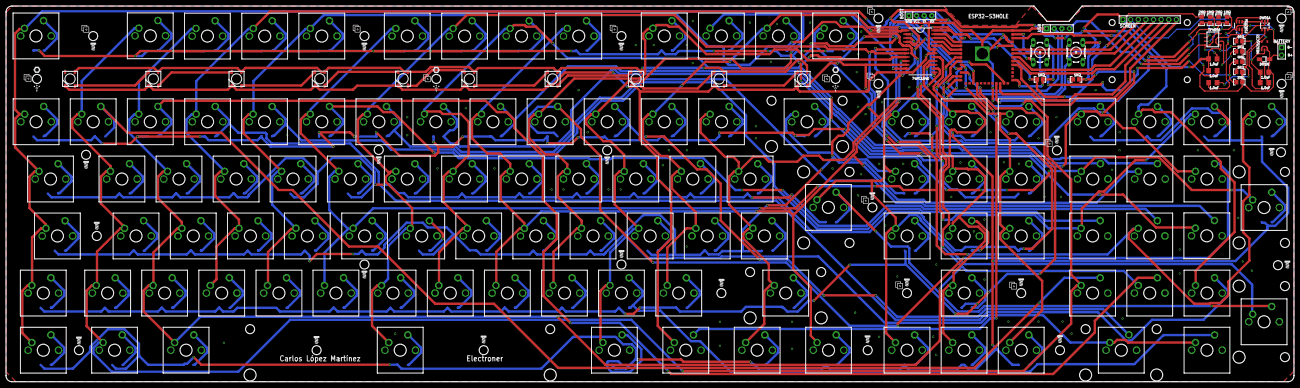
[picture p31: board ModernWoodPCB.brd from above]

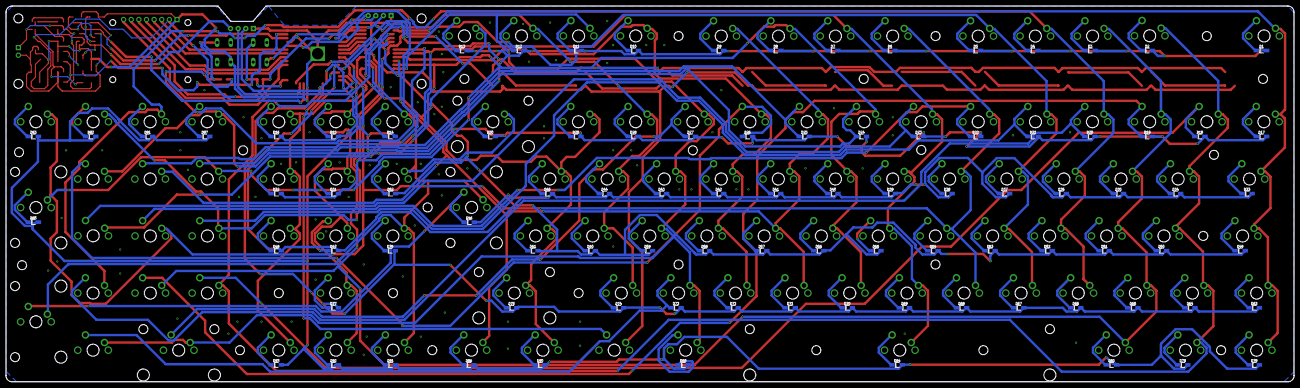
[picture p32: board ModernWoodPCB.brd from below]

Board: 2 copper layers, 428.5 x 125.0 mm, 236 parts (92 on the bottom side), 156 nets.

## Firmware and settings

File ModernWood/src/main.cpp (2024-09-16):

#include <ModernWood.h>

//#define DEBUG

#ifdef DEBUG
#include "driver/temp_sensor.h"
#endif

// ################################################## MAIN ##################################################

void setup()
{
    // Load the all User Preferences configuration from the EEPROM
    configurationModernWood.begin("MWConfig", false);
    loadUserConfiguration();
    configurationModernWood.end();

#ifdef DEBUG
    // TEMPERATURE SENSOR ON CHIP
    temp_sensor_config_t temp_sensor = TSENS_CONFIG_DEFAULT();
    temp_sensor.dac_offset = TSENS_DAC_L2; // TSENS_DAC_L2 is default; L4(-40°C ~ 20°C), L2(-10°C ~ 80°C), L1(20°C ~ 100°C), L0(50°C ~ 125°C)
    temp_sensor_set_config(temp_sensor);
    temp_sensor_start();
#endif

    // Disable WiFi
    WiFi.mode(WIFI_OFF);

#ifdef DEBUG
    Serial.begin(115200);
    Serial.println("ModernWood Keyboard");
#endif

    // Battery
#ifdef BATTERY_CHECK
    // Create a timer object using hw_timer_t
    hw_timer_t *BatteryChecktimer = NULL;
    // Attach onTimer function to our timer.
    // 0 : timer number
    // 80 : 80 divider. 1 tick = 1 micro second. So this will make our timer run at 1Mhz
    // true : Count up
    BatteryChecktimer = timerBegin(0, 80, true);
    timerAttachInterrupt(BatteryChecktimer, &checkBatteryLevel, true);
    timerAlarmWrite(BatteryChecktimer, BATTERY_CHECK_INTERVAL * 1000, true); // 60 seconds interval
    // Enable our timer.
    timerAlarmEnable(BatteryChecktimer);
#endif

    // USB
#ifdef USB_CHECK
    pinMode(PIN_USB_CONNECTED, INPUT_PULLUP);
    attachInterrupt(digitalPinToInterrupt(PIN_USB_CONNECTED), USBConnected, RISING);
    attachInterrupt(digitalPinToInterrupt(PIN_USB_CONNECTED), USBDisconnected, FALLING);
#endif

    // Keyboard
    pinMode(KEYBOARD_DISPLAY_SWITCH, INPUT_PULLUP);
    attachInterrupt(digitalPinToInterrupt(KEYBOARD_DISPLAY_SWITCH), FNKeyboardDisplay, FALLING); // Function KEY Pushed (PullUp)

    pinMode(COD0, OUTPUT);
    pinMode(COD1, OUTPUT);
    pinMode(COD2, OUTPUT);
    pinMode(COD3, OUTPUT);

    pinMode(E0, INPUT_PULLUP);
    pinMode(E1, INPUT_PULLUP);
    pinMode(E2, INPUT_PULLUP);
    pinMode(E3, INPUT_PULLUP);
    pinMode(E4, INPUT_PULLUP);
    pinMode(E5, INPUT_PULLUP);

    // Led Configuration
    LedsColor.CalculateRGB(); // Color is in int format from the EEPROM
    RgbLED.begin();
    float brightness = (*SubMenuBrightnessVar[_BrightnessLeds] / 100.0f);
    for(int i = 0; i < NUMBER_OF_LEDS; i++) {
        RgbLED.setPixelColor(i, (int)(LedsColor.r * brightness),
                                (int)(LedsColor.g * brightness),
                                (int)(LedsColor.b * brightness));
    }
    if (*SubMenuLedsVar[_EnableLeds] == 0)
    {
        RgbLED.clear();
    }
    RgbLED.show();

    // Display
#ifdef DISPLAY_ENABLED
    // Dissable the display Image for noise with BLK_SCREEN pin
    pinMode(BLK_SCREEN, OUTPUT);

    analogWrite(BLK_SCREEN, LOW);
    tft.begin();
    tft.fillScreen(TFT_BLACK);

    tft.setRotation(3);
    tft.setFreeFont(&FreeSansBold9pt7b); // Altura de la fuente 12
    tft.setTextColor(TFT_WHITE);
    delay(50);
    analogWrite(BLK_SCREEN, HIGH);

    // Show in the screen the Image of the keyboard icon in the center 80x80 pixels in the Images.h
    tft.pushImage(40, 0, 80, 80, image_Icon, 0);
    delay(1000);
    tft.fillScreen(TFT_BLACK);

    // Draw a line from 0,24 to 160,24
    tft.drawLine(0, SPLIT_LINE, DISPLAY_HEIGHT, SPLIT_LINE, TFT_WHITE);

    // Show the image_USB in the screen int the position 1,1 33x15 pixels
    tft.fillRect(USB_display_image.x,
                 USB_display_image.y,
                 USB_display_image.width,
                 USB_display_image.height,
                 TFT_BLACK);
    tft.pushImage(USB_display_image.x,
                  USB_display_image.y,
                  USB_display_image.width,
                  USB_display_image.height,
                  image_USB, 0);

    // Show the FNKeyboard
    tft.pushImage(KeyboardFN_display_image.x,
                  KeyboardFN_display_image.y,
                  KeyboardFN_display_image.width,
                  KeyboardFN_display_image.height,
                  image_KeyboardFN, 0);

    // Position the cursor in the position 75,22 and print the text "100%"
    tft.setCursor(BATTERY_LEVEL_X, BATTERY_LEVEL_Y);
    tft.print("100%");

    // Show the image_Battery in the screen int the position 1,127 34x19 pixels
    tft.pushImage(Battery_display_image.x,
                  Battery_display_image.y,
                  Battery_display_image.width,
                  Battery_display_image.height,
                  image_Battery, 0);

    tft.fillRect(Battery_Inside_display_image.x,
                 Battery_Inside_display_image.y,
                 Battery_Inside_display_image.width,
                 Battery_Inside_display_image.height, TFT_GREEN);

    // MENU
    // configuration icons
    for (int i = 0; i < 6; i++)
    {
        printMenuOptionNumber(tft, i, false);
    }

    // Reset the font to the default
    tft.setTextColor(TFT_WHITE, TFT_BLACK);
    tft.setFreeFont(NULL);
    tft.setTextSize(1);

#endif

    // Set the keyboard Functions to noneFN and default
    inExternalFunctionMode = false;
    executingCustomFunction = false;
    actualFunctionRow = 0;
    actualFunctionCol = 0;

    // Energy Save mode
    attachInterrupt(digitalPinToInterrupt(E0), onKeyPress, FALLING);
    attachInterrupt(digitalPinToInterrupt(E1), onKeyPress, FALLING);
    attachInterrupt(digitalPinToInterrupt(E2), onKeyPress, FALLING);
    attachInterrupt(digitalPinToInterrupt(E3), onKeyPress, FALLING);
    attachInterrupt(digitalPinToInterrupt(E4), onKeyPress, FALLING);
    attachInterrupt(digitalPinToInterrupt(E5), onKeyPress, FALLING);

    // Set and activate timer only if EnergySaveMode is true
    if (EnergySaveMode)
    {
        setupTimerEnergySave();
        timerSetupDone = true;
#ifdef DEBUG
        Serial.println("Energy Save Mode Enabled");
#endif
    }
}

void loop()
{
    // Keyboards USB/BLE
    BleKeyboard bleKeyboard("ModernWood", "Electroner", 100);
    USBHIDKeyboard Keyboard;

    // Start USB and BLE Keyboards
    if (BLEEnabled)
    {
        bleKeyboard.begin();
        isBluetoothOn = true;
#ifdef DEBUG
        Serial.println("BLE Keyboard Started");
#endif
    }
    Keyboard.begin();
    USB.begin();

    //Release all keys
    Keyboard.releaseAll();
    if (bleKeyboard.isConnected())
    {
        bleKeyboard.releaseAll();
    }

#ifdef DEBUG
    unsigned int loop_counter = 0;
    unsigned int last_loop_time = millis();
    unsigned int secs = 0;
#endif

    while (true)
    {

#ifdef DEBUG
        // For debug purposes show how many times the loop is executed per second
        loop_counter++;
        if (millis() - last_loop_time > 1000)
        {
            Serial.print("Loop executed ");
            Serial.print(loop_counter);
            Serial.println(" times per second");

            Serial.print("Temperature: ");
            float result = 0;
            temp_sensor_read_celsius(&result);
            Serial.print(result);
            Serial.println(" °C");

            loop_counter = 0;
            last_loop_time = millis();

            secs++;
            Serial.print("Seconds: ");
            Serial.println(secs);

            //Show bluetooth status
            Serial.print("BLE Connected: ");
            Serial.println(bleKeyboard.isConnected());
        }

        // Read from serial
        char c = 'N';
        if (Serial.available())
        {
            c = Serial.read();
            Serial.print("Read from serial: ");
            Serial.println(c);
        }
        // wasd -> ARRIBA ABAJO DERECHA IZQUIERDA
        // Espace -> Enter
        // E -> Escape
        // Q -> MODO ESPECIAL
        switch (c)
        {
        case '1':
            WorkingAsKeyboard = !WorkingAsKeyboard;
            interrupted_FN = true;
            break;

        case '0':
            MenuPressed[ArrEsc] = true;
            break;

        case '5':
            MenuPressed[ArrEnter] = true;
            break;

        case '8':
            MenuPressed[ArrUp] = true;
            break;

        case '2':
            MenuPressed[ArrDown] = true;
            break;

        case '4':
            MenuPressed[ArrLeft] = true;
            break;

        case '6':
            MenuPressed[ArrRight] = true;
            break;

        case '1':
            batteryLevel--;
            batteryLevelChanged = true;
            break;

        case '2':
            batteryLevel++;
            batteryLevelChanged = true;
            break;

        case '3':
            connectionChanged = true;
            isUSBPreferred = !isUSBPreferred;
            isBLEPreferred = !isBLEPreferred;
            break;

        case '4':
            connectionChanged = true;
            isBLEConnected = !isBLEConnected;
            break;

        case '5':
            bleKeyboard.write

        case ' ':
            bleKeyboard.write(KEY_ESPACIO);

        case 'A':
            bleKeyboard.write(KEY_A);

        case 'B':
            bleKeyboard.write(KEY_B);

        case 'C':
            bleKeyboard.write(KEY_C);

        default:
            break;
        }

#endif

        // ################################################## LOOP LOGIC ##################################################
        // Energy Save mode logic
        // If the Energy Save mode is enabled, enable the timer
        if (EnergySaveMode && !timerSetupDone)
        {
#ifdef DEBUG
            Serial.println("Energy Save Mode Enabled");
#endif
            setupTimerEnergySave();
            timerSetupDone = true;
        }
        else if (!EnergySaveMode && timerSetupDone)
        {
#ifdef DEBUG
            Serial.println("Energy Save Mode Disabled");
#endif
            // If the Energy Save mode is disabled, disable the timer
            if (EnergyModetimer != NULL)
            {
                timerAlarmDisable(EnergyModetimer);
                timerEnd(EnergyModetimer);
                EnergyModetimer = NULL;
                timerSetupDone = false;
#ifdef DEBUG
                Serial.println("Timer Disabled");
#endif
            }
        }
        if (goingToSleep && !Sleeping)
        {
            // Call the function to go to sleep
            enterEnergySaveMode();
        }
        if (Sleeping && !goingToSleep)
        {
            // Call the function to wake up
            wakeupHandler();
        }

        // Battery logic to update the battery level
        if (batteryLevelChanged && BatteryEnabled && !Sleeping)
        {
#ifdef DEBUG
            // If the battery level is less than 0% set it to 0%
            if (batteryLevel < 0)
            {
                batteryLevel = 0;
            }
            // If the battery level is more than 100% set it to 100%
            if (batteryLevel > 100)
            {
                batteryLevel = 100;
            }
#endif

            tft.setFreeFont(&FreeSansBold9pt7b); // Altura de la fuente 12
            tft.setTextColor(TFT_WHITE);

            // Print black the battery level in the screen and the percentage
            tft.fillRect(Battery_Inside_display_image.x,
                         Battery_Inside_display_image.y,
                         Battery_Inside_display_image.width,
                         Battery_Inside_display_image.height, TFT_BLACK);
            tft.fillRect(BATTERY_LEVEL_X,
                         BATTERY_LEVEL_Y - BATTERY_LEVEL_HEIGHT - 1,
                         BATTERY_LEVEL_WIDTH,
                         BATTERY_LEVEL_HEIGHT + 2, TFT_BLACK);

            tft.setCursor(BATTERY_LEVEL_X, BATTERY_LEVEL_Y);
            if (batteryLevel == 100)
            {
                tft.print(String(batteryLevel) + "%");
            }
            else if (batteryLevel < 100 && batteryLevel >= 10)
            {
                tft.print(String(batteryLevel) + " %");
            }
            else if (batteryLevel < 10)
            {
                tft.print(String(batteryLevel) + "  %");
            }
            batteryLevelChanged = false;

            // Print black rectangle to erase the battery level
            tft.fillRect(Battery_Inside_display_image.x,
                         Battery_Inside_display_image.y,
                         Battery_Inside_display_image.width,
                         Battery_Inside_display_image.height, TFT_BLACK);
            RGB percolor;
            percolor.r = 255 - (255 * batteryLevel) / 100;
            percolor.g = (255 * batteryLevel) / 100;
            percolor.b = 0;
            percolor.CalculateColor();
            // Print the battery level in the screen
            tft.fillRect(Battery_Inside_display_image.x,
                         Battery_Inside_display_image.y,
                         static_cast<int>(Battery_Inside_display_image.width * (batteryLevel / 100.0f)),
                         Battery_Inside_display_image.height, percolor.color);

            // Reset the font to the default
            tft.setFreeFont(NULL);
            tft.setTextSize(1);

            // Update the bleKeyboard battery level
            bleKeyboard.setBatteryLevel(batteryLevel);
        }

        // Check if the leds are enabled
        if (*SubMenuLedsVar[_EnableLeds] != 0 && !Sleeping)
        {
            // Check for special functions like led control
            if (*SubMenuLedsVar[_LedsMode] != 0)
            {
                // Check if the led mode is white
                if (*SubMenuLedsVar[_LedsMode] == 1)
                {
                    // Show white color
                    float brightness = (*SubMenuBrightnessVar[_BrightnessLeds] / 100.0f);
                    for (int i = 0; i < NUMBER_OF_LEDS; i++)
                    {
                        RgbLED.setPixelColor(i, (int)(255 * brightness),
                                             (int)(255 * brightness),
                                             (int)(255 * brightness));
                    }
                    if (*SubMenuLedsVar[_EnableLeds] == 0)
                    {
                        RgbLED.clear();
                    }
                    RgbLED.show();
                }
                // Check if the led mode is rainbow
                if (*SubMenuLedsVar[_LedsMode] == 2)
                {
                    // Check if the led mode is rainbow
                    rainbowEffect(RgbLED);
                }
            }
        }

        // Connection logic to update the connection status
        if (*SubMenuConnectionVar[_PreferenceUSB] && connectionChanged && !Sleeping)
        {
            tft.fillRect(BLE_display_image.x,
                         BLE_display_image.y,
                         BLE_display_image.width,
                         BLE_display_image.height,
                         TFT_BLACK);
            tft.fillRect(Connection_display_image.x,
                         Connection_display_image.y,
                         Connection_display_image.width,
                         Connection_display_image.height,
                         TFT_BLACK);
            tft.pushImage(USB_display_image.x,
                          USB_display_image.y,
                          USB_display_image.width,
                          USB_display_image.height,
                          image_USB, 0);
            connectionChanged = false;
        }
        else if (connectionChanged && !Sleeping)
        {
            tft.fillRect(USB_display_image.x,
                         USB_display_image.y,
                         USB_display_image.width,
                         USB_display_image.height,
                         TFT_BLACK);
            tft.pushImage(BLE_display_image.x,
                          BLE_display_image.y,
                          BLE_display_image.width,
                          BLE_display_image.height,
                          image_BLE, 0);
            // If bluetooth has a connection show the bluetooth connection image
            if (isBLEConnected && !Sleeping)
            {
                tft.pushImage(Connection_display_image.x,
                              Connection_display_image.y,
                              Connection_display_image.width,
                              Connection_display_image.height,
                              image_Connection, 0);
            }
            else if(!Sleeping)
            {
                tft.fillRect(Connection_display_image.x,
                             Connection_display_image.y,
                             Connection_display_image.width,
                             Connection_display_image.height,
                             TFT_BLACK);
            }
            connectionChanged = false;
        }

        // TODO: Review WorkingAsKeyboard logic in the next lines
        // Display logic to update the display on/off and brightness
        if (*SubMenuConfigVar[_EnableDisplayOption] && displayChanged && !Sleeping)
        {
            // Set the brightness of the screen (ON)
            analogWrite(BLK_SCREEN, (int)(*SubMenuBrightnessVar[_BrightnessDisplay] * 2.55));
            displayChanged = false;
        }
        else if (displayChanged && !Sleeping && WorkingAsKeyboard)
        {
            // Display OFF
            analogWrite(BLK_SCREEN, LOW);
            displayChanged = false;
        }

        if(bleKeyboard.isConnected() && !isBLEConnected)
        {
            isBLEConnected = true;
            connectionChanged = true;
        }
        else if(!bleKeyboard.isConnected() && isBLEConnected)
        {
            isBLEConnected = false;
            connectionChanged = true;
        }

        if(Sleeping && goingToSleep && displayChanged)
        {
            // Display OFF
            analogWrite(BLK_SCREEN, LOW);
            displayChanged = false;
        }

        // ################################################## KEYBOARD LOGIC ##################################################
        // Check if keyboard is executing a custom function
        if (inExternalFunctionMode)
        {
            if (executingCustomFunction)
            {
                (*MODULESFUNCARRAY[actualFunctionRow][actualFunctionCol])();
            }
            else
            {
                if (interrupted_FN)
                {
                    displayChanged = true;

                    // Erase all the screen and print the general display
                    printGeneralDisplay(tft);

                    // Reset the Macro and special function variables
                    actualFunctionRow = 0;
                    actualFunctionCol = 0;
                    inExternalFunctionMode = false;
                    executingCustomFunction = false;
                    interrupted_FN = false;
                }
                WorkingInExternalFunctionMode(tft, bleKeyboard, Keyboard, isBLEConnected, isUSBConnected);
            }
        }
        else
        {
            // Check if keyboard is working as Display Mode or Keyboard Mode
            // Also check if is USBPreferred or BLEPreferred
            if (WorkingAsKeyboard)
            {
                // From Display to Keyboard Mode
                if (interrupted_FN)
                {
                    displayChanged = true;

                    tft.fillRect(KeyboardFN_display_image.x,
                                 KeyboardFN_display_image.y,
                                 KeyboardFN_display_image.width,
                                 KeyboardFN_display_image.height,
                                 TFT_BLACK);
                    tft.pushImage(KeyboardFN_display_image.x,
                                  KeyboardFN_display_image.y,
                                  KeyboardFN_display_image.width,
                                  KeyboardFN_display_image.height,
                                  image_KeyboardFN, 0);
                    interrupted_FN = false;

                    // Erase all the screen and print the general display
                    printGeneralDisplay(tft);

                    // Repaint all the menu icons
                    for (int i = 0; i < 6; i++)
                    {
                        printMenuOptionNumber(tft, i, false);
                    }

                    // Here in the back to the Keyboard Mode we save the configuration if changed has been made
                    // Save the changes in the EEPROM opening the configuration descriptor
                    if (ChangedConfig)
                    {
                        if (!configurationReseted)
                        {
                            saveUserConfiguration();
#ifdef DEBUG
                            Serial.println("Configuration Saved");
#endif
                        }
                        else
                        {
                            // If no double press we dont reset the configuration
                            configurationReseted = false;
                        }

                        ChangedConfig = false;
                    }

                    // Function to set configuration of the keyboard (check BLEEnabled)
                    if (!BLEEnabled && isBluetoothOn)
                    {
#ifdef DEBUG
                        Serial.println("BLE Keyboard Stopped FN 1");
#endif
                        bleKeyboard.end();
                        //TURN OFF THE BLUETOOTH
                        btStop();
                        isBluetoothOn = false;
                    }
                    else if (BLEEnabled && !isBluetoothOn)
                    {
#ifdef DEBUG
                        Serial.println("BLE Keyboard Started FN 1");
#endif
                        btStart();
                        bleKeyboard.begin();
                        isBluetoothOn = true;
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

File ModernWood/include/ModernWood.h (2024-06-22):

#pragma once

#include <Arduino.h>
#include <math.h>
#include <algorithm>
#include <USB.h>
#include <USBHIDKeyboard.h>
#include <BleKeyboard.h>
#include <SPI.h>
#include <TFT_eSPI.h>
// For wifi disable
#include <WiFi.h>
#include "esp_bt.h"
#include "esp_bt_main.h"
#include <Adafruit_NeoPixel.h>
#include <NimBLEDevice.h>

#include <Keys.h>
#include <Images.h>

#include <Extra.h>
#include <customRGB.h>

#include <Preferences.h>
#include <esp_sleep.h>

//Modules
#include "ModulesMap.h"

// ################################################## CONFIGURATION PREFERENCES ##################################################

extern Preferences configurationModernWood;
extern bool ChangedConfig;

void loadUserConfiguration(int Menu, int Option);
void loadUserConfiguration();

void saveUserConfiguration(int Menu, int Option);
void saveUserConfiguration();

// ################################################## LED INDICATOR ##################################################

#define LED_INDICATOR_ENABLED
#define PIN_LED_INDICATOR 48 //Pin used to control the 
#define NUMBER_OF_LEDS 10
extern Adafruit_NeoPixel RgbLED;

extern int LedsBrightness;
extern int LedsActive;
extern RGB LedsColor;
extern int LedsMode;
extern int LedsSpeed;
const float HueStep = 0.01;
const float Saturation = 1.0;
const float ValueBrightness = 1.0;

extern int interval;
extern unsigned long lastUpdateTimeRainbow;

// ################################################## BATTERY ##################################################

#define BATTERY_CHECK //Define if we want to check the battery level
#define PIN_BATTERY 1 //Pin used to read the battery level
#define BATTERY_DIVIDER_VOLTAGE 3.7
#define BATTERY_DIVIDER_VOLTAGE_DISCHARGED 3.3

#define BATTERY_DIVIDER_RESISTOR1 270000
#define BATTERY_DIVIDER_RESISTOR2 1000000
#define BATTERY_CHECK_INTERVAL 60000 // ms

extern int BatteryEnabled;
extern uint8_t volatile batteryLevel;
extern uint8_t volatile batteryLevelLast;
extern bool batteryLevelChanged;
extern portMUX_TYPE timerMux;

void IRAM_ATTR checkBatteryLevel();

//Energy Save Mode
#define ENERGY_SAVE_MODE_TIME 300 // 5 minutes

extern int EnergySaveMode;
extern bool goingToSleep;
extern bool Sleeping;
extern bool timerSetupDone;
extern hw_timer_t *EnergyModetimer;
extern unsigned long lastKeyPressTime;

void IRAM_ATTR onKeyPress();
void setupTimerEnergySave();
void checkEnergySaveMode();
void enterEnergySaveMode();
void wakeupHandler();

// ################################################## USB HID ##################################################

#define USB_CHECK
#define PIN_USB_CONNECTED 2 //Pin used by the tp4056 to indicate that the battery is charging and the USB is connected

extern int BLEEnabled;
extern int isBLEPreferred;
extern int isUSBPreferred;
extern bool connectionChanged; // For changing the display when the connection changes
extern bool isBluetoothOn;

extern bool volatile isUSBConnected;
extern bool volatile isBLEConnected;

void IRAM_ATTR USBConnected();

void IRAM_ATTR USBDisconnected();

// ################################################## DISPLAY ##################################################

//#define TFT_SCL 42  	// Pin SPI Clock (SCLK)
//#define TFT_SDA 41  	// Pin SPI out data (MOSI)
//#define TFT_RES 40    // Pin restart (RST)
//#define TFT_DC 39     // Pin data selection (DC)
//#define TFT_CS 38    	// Pin SPI selection chip (CS)
#define BLK_SCREEN 47   // GND -> OFF

//0,0							160,0
//X---------------------------X
//|							|
//|							|
//|							|
//|							|
//X---------------------------X
//0,80						160,80


#define DISPLAY_ENABLED
#define DISPLAY_WIDTH 80
#define DISPLAY_HEIGHT 160
#define DISPLAY_ROTATION 0
extern TFT_eSPI tft;
extern int DisplayEnabled;
extern int LanguageMenu;
extern int DisplayBrightness;
extern bool displayChanged;

// ################################################## KEYBOARD ##################################################

#define KEYBOARD_DISPLAY_SWITCH 10
#define DEBOUNCE_DELAY_FN 200

extern bool volatile WorkingAsKeyboard;
extern bool volatile interrupted_FN;
//millis var to debounce
extern unsigned int volatile last_interrupt_FN_time;

extern int KeyboardEnabled;

void IRAM_ATTR FNKeyboardDisplay();

// ################################################## OTHER ##################################################

extern bool inExternalFunctionMode; //To know if we are in the external function mode
extern bool executingCustomFunction; //To know if we are executing a custom function
//If there is a actual function begin exectued, which is the row and col of the key
extern int actualFunctionRow; 
extern int actualFunctionCol;

extern bool configurationReseted;

#define COD0 4  //Output pin X0 (GPIO4)
#define COD1 5  //Output pin X1 (GPIO5)
#define COD2 6  //Output pin X2 (GPIO6)
#define COD3 7  //Output pin X3 (GPIO7)

#define E0 15   //Input pin E0 
#define E1 16   //Input pin E1 
#define E2 17   //Input pin E2 
#define E3 18   //Input pin E3
#define E4 8    //Input pin E4
#define E5 9    //Input pin E5

// Array de lectura de Fila
const unsigned int ESwitch[KEYBOARDHEIGHT] = {E0, E1, E2, E3, E4, E5}; 

extern int TiempoDebounce;
extern bool SwitchState[KEYBOARDHEIGHT][KEYBOARDWIDTH];
extern bool SwitchLastState[KEYBOARDHEIGHT][KEYBOARDWIDTH];
extern unsigned long Debounce[KEYBOARDHEIGHT][KEYBOARDWIDTH];

//Config And menu
enum KeysDistribution {ArrEnter, ArrUp, ArrLeft, ArrDown, ArrRight, ArrEsc};
enum Menus {MenuConfig, MenuBrightness, MenuLeds, MenuEnergy, MenuConnection, MenuInfoHelp};

//Size of the Submenus (number of options, the last one is the size of the submenu, and has to be the last one)
enum SubMenuConfig {_EnableDisplayOption, _EnableKeyboardOption, _DebounceOption, _LanguageMenuOption, SizeSubMenuConfig};
const String SubMenuConfigText[SizeSubMenuConfig] = {"Enable Display", "Enable Keyboard", "Debounce (ms)", "Language"};
const String SubMenuConfigKeys[SizeSubMenuConfig] = {"ENADIS", "ENAKEY", "DEBNCE", "LANGUA"};
const String SubMenuConfigVarType[SizeSubMenuConfig] = {"bool", "bool", "int", "language"};
extern int* SubMenuConfigVar[SizeSubMenuConfig];

enum SubMenuBrightness {_BrightnessLeds, _BrightnessDisplay, SizeSubMenuBrightness}; 
const String SubMenuBrightnessText[SizeSubMenuBrightness] = {"Brightness Leds", "Brightness Display"};
const String SubMenuBrightnessKeys[SizeSubMenuBrightness] = {"BRILED", "BRIDIS"};
const String SubMenuBrightnessVarType[SizeSubMenuBrightness] = {"int", "int"};
extern int* SubMenuBrightnessVar[SizeSubMenuBrightness];

enum SubMenuLeds {_EnableLeds, _LedsColor, _LedsMode, _LedsSpeed, SizeSubMenuLeds};
const String SubMenuLedsText[SizeSubMenuLeds] = {"Enable Leds", "Leds Color", "Leds Mode", "Leds Speed"};
const String SubMenuLedsKeys[SizeSubMenuLeds] = {"ENALED", "LEDCOL", "LEDMOD", "LEDSPE"};
const String SubMenuLedsVarType[SizeSubMenuLeds] = {"bool", "rgb", "int", "int"};
extern int* SubMenuLedsVar[SizeSubMenuLeds];
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

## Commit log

2023-06-28 All interruptions done
2023-07-03 Animations and Screen battery and connections tested
2023-07-03 Added the Icons and the screen is now working
    [Modern Wood.dwg, PCB.brd, PCB.sch]
2023-07-04 Fixed Interruptions and FN mode for Keyboard
    [Images.h, main.cpp]
2023-07-09 Pins fixed 8 and 2
    [ModernWood.cpp, ModernWood.h, main.cpp]
2023-08-01 Added The inverted images and selecctor for the menu
    [Images.h, ModernWood.cpp, ModernWood.h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]
2023-08-04 Fixed Function for printing, added enter and ESC working
    [Images.h, ModernWood.cpp, ModernWood.h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]
2023-08-15 Added The menu suboptions and make it scalable, Minor Fixes
    [Images.h, ModernWood.cpp, ModernWood.h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]
2023-09-11 Added the schematic of the pcb autocad
    [New Tiny.dwg]
2023-09-14 Fixed minor bugs and added Varible Show correctly in menu
    [ModernWood.cpp, ModernWood.h, main.cpp]
2023-09-29 Turned built in led on for debug
2023-10-09 New directory and changed the tiny dxf sketch
    [New Tiny.dwg]
2023-10-10 Added the modules folder and configured the project added also a Version example
    [New Tiny.dwg]
2023-10-18 Fixed Inline error with exitModule() Function and added temperature Monitoring.
    [New Tiny.dwg]
2023-10-18 Changed The autocad Sketch
    [New Tiny.dwg]
2023-10-18 Added the 3º view on the Sketch
    [New Tiny.dwg]
2023-10-24 Changed PCB and added the TP4056 Parts, also changed diode types.
    [New Tiny.dwg, New Tiny.dxf, SpecialHoles.dxf]
2023-10-28 Created the Led hole for keys library.
    [PCB.brd]
2023-11-04 Make the connections for the Battery and Power circuits
    [PCB.brd, PCB.sch]
2023-11-23 Make the screen DXF and added it to .pcb board
    [New Tiny.dwg, PCB.brd]
2023-11-23 Changed Capacitor and resistor type
    [PCB.brd, PCB.sch]
2023-11-24 Added the esp32 chip connections lines in .sch
    [PCB.brd, PCB.sch]
2023-11-25 Finished the power circuit for the keyboard
    [PCB.brd, PCB.sch]
2023-11-25 Finished .sch
    [New Tiny.dwg, PCB.brd, PCB.sch]
2023-11-26 Added new holes and changed the pcb layaout to fit the usb connector
    [New Tiny.dwg, PCB.brd, PCB.sch]
2023-11-27 Finished PCB Board and Schematic
    [New Tiny.dwg, PCB.sch, PCBGNDPlane.brd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]
2023-11-28 Fixed PCB holes and dimensions, improved GND Plane. Ready for Production
    [ModernWoodPCB.brd, ModernWoodPCB.sch, New Tiny.dwg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]
2023-11-28 Created the Parts file and the step file
    [ModernWoodPCB.step]
2023-11-30 Fixed Leds datasheet
2024-02-20 Revision 2 of PCB and Finished
    [ModernWoodPCB.brd, ModernWoodPCB.sch, Parts.csv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]
2024-02-20 Added Mark for JLCPB
    [ModernWoodPCB.brd, ModernWoodPCB.step]
2024-02-21 Fixed 5V on Tp4056 status pins
    [ModernWoodPCB.brd, ModernWoodPCB.sch]
2024-02-21 Added Text to PCB
    [ModernWoodPCB.brd]
2024-02-22 Fixed value texts for smd resistors
    [ModernWoodPCB.brd, ModernWoodPCB.sch]
2024-02-22 Updated Parts.txt for new resistors
    [Parts.csv]
2024-02-22 Updated all doccuments related to PCB
2024-02-22 Removed a error in PCB Silkscreen layer
2024-04-04 New review of Schematic and added a voltage regulator diode protection
    [ModernWoodPCB.brd, ModernWoodPCB.sch]
2024-04-17 Added an option to control debug from a host keyboard
    [New Tiny.dwg]
2024-04-17 Added Rainbow Mode for leds. Also make ble enable dissable.
2024-04-17 Fixed on/off bluetooth keyboard
    [main.cpp]
2024-05-16 Fixed led color and EEPROM loading color, also adjusted the voltaje of battery mapping
    [ModernWood.cpp, main.cpp]
2024-05-22 Added HSV Color and better led performance.
2024-05-23 Done creating the power save mode
2024-05-28 Added define for sleep time and fixed ble battery update
    [ModernWood.cpp, ModernWood.h, main.cpp]
2024-06-01 Fixed leds and minors logics
    [ModernWood.cpp, main.cpp]
2024-06-10 Fixed ble initialization and on/off
    [ModernWood.cpp, ModernWood.h, main.cpp]
2024-06-22 Added the product images
    [Agujeros Especiales.dxf, Difusor.dwg, Difusor.dxf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]
2024-07-01 Minor Fixes for starting up the board with low amperage
    [ModernWood.cpp]
2024-09-16 Fixed minor screen bugs when editing config
    [ModernWood.cpp, main.cpp]

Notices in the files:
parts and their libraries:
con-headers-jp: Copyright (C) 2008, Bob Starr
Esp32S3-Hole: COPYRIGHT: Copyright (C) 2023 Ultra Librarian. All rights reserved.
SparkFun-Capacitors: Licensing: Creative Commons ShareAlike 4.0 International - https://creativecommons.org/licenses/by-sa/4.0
